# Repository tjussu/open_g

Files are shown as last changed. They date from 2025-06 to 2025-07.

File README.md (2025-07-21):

# OpenG Project

__Currently, the project is in the prototyping phase.__

## Overview

The goal of this project is to develop an open-source data logger for soaring and glider aerobatics. The hardware can be built by anyone interested and modified for their own purposes.

## Goals
Specific implementation goals are:

- A watchdog for structural load factors:
    - The load factors are measured in correspondence with the flight envelope (speed & load factors).
    - Critical events will be saved to memory.
    - The load factors can be displayed on a module.
- Path tracing for aerobatics:
    - Tracking of the flight path for training evaluation.
- Easy construction:
    - No difficult-to-solder SMD parts.
    - PCB can be ordered from an online EMS.
    - 3D-printable casing.
    - Construction cost under 450 €.
    - Easy modification.
- Documentation:
    - Hardware documentation.
    - Software documentation.
    - User manual.
    - Technical reference.

We aim to design the hardware in such a way that the system is compliant with EASA regulations. 

## Collaboration
The project is part of a master's thesis conducted at the _Dortmund University of Applied Sciences and Arts_ in cooperation with the _Luftsportfreunde 2000 Kamen/Dortmund club_.

Thanks to both!

## Future Updates
Further information will be provided in the near future.

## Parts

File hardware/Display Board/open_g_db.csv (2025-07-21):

Reference | Value | Qty | Footprint | DNP | Exclude from BOM | Exclude from Board | Datasheet | Mouser Price/Stock
C1,C2,C6,C7 | 0.1u | 4 | Capacitor_SMD:C_0805_2012Metric_Pad1.18x1.45mm_HandSolder |  |  |  | ~
C3 | 1u | 1 | Capacitor_SMD:C_0805_2012Metric_Pad1.18x1.45mm_HandSolder |  |  |  | ~
C4 | 10u | 1 | Capacitor_THT:CP_Radial_D5.0mm_P2.00mm |  |  |  | https://www.we-online.com/components/products/datasheet/860020672010.pdf
C5 | 22u | 1 | Capacitor_THT:CP_Radial_D5.0mm_P2.00mm |  |  |  | https://www.we-online.com/components/products/datasheet/860020672011.pdf
C8 | 22u | 1 | Capacitor_SMD:C_0805_2012Metric_Pad1.18x1.45mm_HandSolder |  |  |  | ~
C9 | 10u | 1 | Capacitor_THT:CP_Radial_D5.0mm_P2.00mm | Nicht bestücken |  |  | https://www.we-online.com/components/products/datasheet/860020672010.pdf
C10 | 22u | 1 | Capacitor_THT:CP_Radial_D5.0mm_P2.00mm | Nicht bestücken |  |  | https://www.we-online.com/components/products/datasheet/860020672011.pdf
C11 | 47n | 1 | Capacitor_SMD:C_0805_2012Metric_Pad1.18x1.45mm_HandSolder |  |  |  | ~
D2 | PWR_LED | 1 | LED_THT:LED_D3.0mm_Horizontal_O1.27mm_Z2.0mm_Clear |  |  |  | https://www.mouser.de/datasheet/2/216/WP710A10SGC-50126.pdf
D4,D5,D6 | LED_wh | 3 | LED_THT:LED_D3.0mm_Horizontal_O1.27mm_Z2.0mm_Clear |  |  |  | https://www.mouser.de/datasheet/2/414/OVLAW4CB7-3011932.pdf
D7,D8,D9 | LED_gr | 3 | LED_THT:LED_D3.0mm_Horizontal_O1.27mm_Z2.0mm_Clear |  |  |  | https://www.mouser.de/datasheet/2/216/WP710A10SGC-50126.pdf
D10,D11,D12,D13,D14,D15 | LED_or | 6 | LED_THT:LED_D3.0mm_Horizontal_O1.27mm_Z2.0mm_Clear |  |  |  | https://www.mouser.de/datasheet/2/216/WP710A10SGC-50126.pdf
D16 | LED_rd | 1 | LED_THT:LED_D3.0mm_Horizontal_O1.27mm_Z2.0mm_Clear |  |  |  | https://www.mouser.de/datasheet/2/216/WP710A10SGC-50126.pdf
F1 | Fuse | 1 | SamacSys_Parts:3557-2 |  |  |  | https://www.mouser.de/datasheet/2/215/M65p41-3517744.pdf
H1,H2 | MountingHole | 2 | MountingHole:MountingHole_5mm_Pad_Via |  | Von Bauteilliste ausgeschlossen |  | ~
J1 | DE9_Socket | 1 | SamacSys_Parts:NFD17E09SAFC1DA |  |  |  | ~
R1,R6,R9,R11,R12,R20,R21,R22,R43,R44,R45,R46,R47,R48,R49,R50,R51,R52 | 0R | 18 | Resistor_SMD:R_0805_2012Metric_Pad1.20x1.40mm_HandSolder | Nicht bestücken |  |  | ~
R2 | 510 | 1 | Resistor_SMD:R_0805_2012Metric_Pad1.20x1.40mm_HandSolder |  |  |  | ~
R3,R4 | 1k | 2 | Resistor_SMD:R_0805_2012Metric_Pad1.20x1.40mm_HandSolder |  |  |  | ~
R5,R7,R10,R17,R18,R19,R33,R34,R35,R36,R37,R38,R39,R40,R41,R42 | 10k | 16 | Resistor_SMD:R_0805_2012Metric_Pad1.20x1.40mm_HandSolder |  |  |  | ~
R8 | 100k | 1 | Resistor_SMD:R_0805_2012Metric_Pad1.20x1.40mm_HandSolder |  |  |  | ~
R13 | 0R | 1 | Resistor_SMD:R_0805_2012Metric_Pad1.20x1.40mm_HandSolder |  |  |  | ~
R14,R15,R16 | 82 | 3 | Resistor_SMD:R_0805_2012Metric_Pad1.20x1.40mm_HandSolder |  |  |  | ~
R23,R24,R25,R26,R27,R28,R29,R30,R31,R32 | 130 | 10 | Resistor_SMD:R_0805_2012Metric_Pad1.20x1.40mm_HandSolder |  |  |  | ~
TP1,TP2,TP3,TP4,TP5,TP6,TP7,TP8,TP9,TP10,TP11 | TestPoint | 11 | TestPoint:TestPoint_Pad_D2.5mm |  |  |  | ~
U1 | ESP32-WROOM-32E | 1 | RF_Module:ESP32-WROOM-32E |  |  |  | https://www.espressif.com/sites/default/files/documentation/esp32-wroom-32e_esp32-wroom-32ue_datasheet_en.pdf
U2 | MAX7318AWG+ | 1 | Package_SO:SOIC-24W_7.5x15.4mm_P1.27mm |  |  |  | https://www.mouser.de/datasheet/2/609/1/MAX7318-3470766.pdf
IC1,IC2 | TS04-66-75-BK-160-SMT | 2 | SamacSys_Parts:TS046675BK160SMT |  |  |  | https://www.sameskydevices.com/product/resource/supplyframepdf/ts04.pdf | https://www.mouser.co.uk/ProductDetail/CUI-Devices/TS04-66-75-BK-160-SMT?qs=A6eO%252BMLsxmR5CIauYOve0Q%3D%3D
S1 | 1MS1T1B4M7QES | 1 | SamacSys_Parts:1MS1T1B4M7QES |  |  |  | https://www.dailywell.com.tw/en/search/index.html?q=1MS1T1B4M7QES&type=all | https://www.mouser.co.uk/ProductDetail/Dailywell/1MS1T1B4M7QES?qs=B6kkDfuK7%2FAUibuiVO%252BdHA%3D%3D
Q1,Q2,Q3,Q4,Q5,Q6,Q7,Q8,Q9,Q10,Q11,Q12,Q13,Q14 | BC548A | 14 | SamacSys_Parts:BC548A |  |  |  | https://diotec.com/request/datasheet/bc546.pdf | https://www.mouser.co.uk/ProductDetail/Diotec-Semiconductor/BC548A?qs=OlC7AqGiEDn7ksXHluy35w%3D%3D
PS1 | N7803-1C | 1 | SamacSys_Parts:N78031C |  |  |  | https://www.meanwell.com/webapp/product/search.aspx?prod=N78 | https://www.mouser.co.uk/ProductDetail/MEAN-WELL/N7803-1C?qs=7D1LtPJG0i1K0F21XTLD8Q%3D%3D
PS2 | N7805-1PH | 1 | SamacSys_Parts:N78031C | Nicht bestücken |  |  | https://www.meanwell.com/webapp/product/search.aspx?prod=N78 | https://www.mouser.co.uk/ProductDetail/MEAN-WELL/N7805-1PH?qs=7D1LtPJG0i2yQtENgJv8Bw%3D%3D
D3 | MMBD352WT1G | 1 | SamacSys_Parts:SOT65P220X100-3N | Nicht bestücken |  |  | https://www.onsemi.com/pub/Collateral/MMBD352WT1-D.PDF | https://www.mouser.co.uk/ProductDetail/ON-Semiconductor/MMBD352WT1G?qs=HVbQlW5zcXX4Hbj73AzZEQ%3D%3D
LS1 | CMI-0955-03TH | 1 | SamacSys_Parts:CMI095503TH |  |  |  | https://www.sameskydevices.com/product/resource/supplyframepdf/cmi-0955-03th.pdf | https://www.mouser.co.uk/ProductDetail/Same-Sky/CMI-0955-03TH?qs=olJun0bQHM8qnyh30s0SwQ%3D%3D
D1 | STPS8H100D | 1 | SamacSys_Parts:TO515P460X1020X2008-2P |  |  |  | http://www.st.com/web/en/resource/technical/document/datasheet/CD00001293.pdf | https://www.mouser.co.uk/ProductDetail/STMicroelectronics/STPS8H100D?qs=JV7lzlMm3yLc5UJZDGTzhw%3D%3D
J2 | 2-1825027-0 | 1 | SamacSys_Parts:218250270 |  |  |  | https://www.mouser.de/datasheet/2/418/8/ENG_CD_1825027_H1-2020946.pdf | https://www.mouser.co.uk/ProductDetail/TE-Connectivity-PB/2-1825027-0?qs=sLzr0G66nuqhlS4AJQmBZQ%3D%3D

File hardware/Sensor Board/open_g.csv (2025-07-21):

Reference | Value | Qty | Footprint | DNP | Exclude from BOM | Exclude from Board | Datasheet | Mouser Price/Stock
TP1,TP2,TP3,TP4,TP5,TP6,TP7,TP8,TP9,TP10,TP11,TP12,TP13,TP14,TP15,TP16 | TestPoint | 16 | TestPoint:TestPoint_Pad_D2.5mm |  |  |  | ~
R4,R5,R6,R7,R8,R11,R13,R15,R16,R17,R22,R23,R25 | 0R | 13 | Resistor_SMD:R_0805_2012Metric_Pad1.20x1.40mm_HandSolder |  |  |  | ~
R12,R14,R18,R19 | 1k | 4 | Resistor_SMD:R_0805_2012Metric_Pad1.20x1.40mm_HandSolder | Nicht bestücken |  |  | ~
R1,R2,R9,R10 | 0R | 4 | Resistor_SMD:R_0805_2012Metric_Pad1.20x1.40mm_HandSolder | Nicht bestücken |  |  | ~
R20,R21,R24 | 1k | 3 | Resistor_SMD:R_0805_2012Metric_Pad1.20x1.40mm_HandSolder |  |  |  | ~
C1,C4,C6 | 0.1u | 3 | Capacitor_SMD:C_0805_2012Metric_Pad1.18x1.45mm_HandSolder |  |  |  | ~
JP1,JP2 | SolderJumper_3_Open | 2 | Jumper:SolderJumper-3_P2.0mm_Open_TrianglePad1.0x1.5mm |  | Von Bauteilliste ausgeschlossen |  | ~
IC1,IC2 | TS04-66-75-BK-160-SMT | 2 | SamacSys_Parts:TS046675BK160SMT |  |  |  | https://www.sameskydevices.com/product/resource/supplyframepdf/ts04.pdf | https://www.mouser.co.uk/ProductDetail/CUI-Devices/TS04-66-75-BK-160-SMT?qs=A6eO%252BMLsxmR5CIauYOve0Q%3D%3D
H1,H2 | MountingHole | 2 | MountingHole:MountingHole_5mm_Pad_Via |  | Von Bauteilliste ausgeschlossen |  | ~
U1 | ESP32-WROOM-32E | 1 | RF_Module:ESP32-WROOM-32D |  |  |  | https://www.espressif.com/sites/default/files/documentation/esp32-wroom-32e_esp32-wroom-32ue_datasheet_en.pdf
R3 | 10k | 1 | Resistor_SMD:R_0805_2012Metric_Pad1.20x1.40mm_HandSolder |  |  |  | ~
PS1 | N7803-1C | 1 | SamacSys_Parts:N78031C |  |  |  | https://www.meanwell.com/webapp/product/search.aspx?prod=N78 | https://www.mouser.co.uk/ProductDetail/MEAN-WELL/N7803-1C?qs=7D1LtPJG0i1K0F21XTLD8Q%3D%3D
J5 | 1861975 | 1 | SamacSys_Parts:PC1861975 |  |  |  | http://www.phoenixcontact.com/de/produkte/1861975/pdf | https://www.mouser.co.uk/ProductDetail/Phoenix-Contact/1861975?qs=tlR8i4ZVbUeb8cFKQBJmmw%3D%3D
J4 | Conn_01x05_Socket | 1 | Connector_PinSocket_2.54mm:PinSocket_1x05_P2.54mm_Vertical |  |  |  | ~
J3 | Conn_01x09_Socket | 1 | Connector_PinSocket_2.54mm:PinSocket_1x09_P2.54mm_Vertical |  |  |  | ~
J2 | DM3CS-SF | 1 | SamacSys:DM3CSSF |  |  |  | https://datasheet.lcsc.com/szlcsc/Hirose-HRS-DM3CS-SF_C202111.pdf | https://www.mouser.co.uk/ProductDetail/Hirose-Connector/DM3CS-SF?qs=tTj%252BmQ3KZwbB9K5zh89Rcw%3D%3D
J1 | DE9_Socket | 1 | SamacSys_Parts:NFD17E09SAFC1DA |  |  |  | https://cdn.amphenol-cs.com/media/wysiwyg/files/documentation/datasheet/inputoutput/io_dsub_standard_density_nfd17.pdf
IC3 | 5525DSO-DB001DS | 1 | Package_SO:SOIC-14W_7.5x9mm_P1.27mm |  |  |  | https://www.te.com/commerce/DocumentDelivery/DDEController?Action=srchrtrv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 | https://www.mouser.co.uk/ProductDetail/Measurement-Specialties/5525DSO-DB001DS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
C8 | 100n | 1 | Capacitor_SMD:C_0805_2012Metric_Pad1.18x1.45mm_HandSolder |  |  |  | ~
C7 | 22u | 1 | Capacitor_SMD:C_0805_2012Metric_Pad1.18x1.45mm_HandSolder |  |  |  | ~
C5 | 1u | 1 | Capacitor_SMD:C_0805_2012Metric_Pad1.18x1.45mm_HandSolder |  |  |  | ~
C3 | 22u | 1 | Capacitor_THT:CP_Radial_D5.0mm_P2.00mm |  |  |  | https://www.mouser.de/ProductDetail/Wurth-Elektronik/860010272001?qs=0KOYDY2FL2%252BONnZKgxEFWA%3D%3D
C2 | 10u | 1 | Capacitor_THT:CP_Radial_D5.0mm_P2.00mm |  |  |  | https://www.we-online.com/components/products/datasheet/860020672010.pdf

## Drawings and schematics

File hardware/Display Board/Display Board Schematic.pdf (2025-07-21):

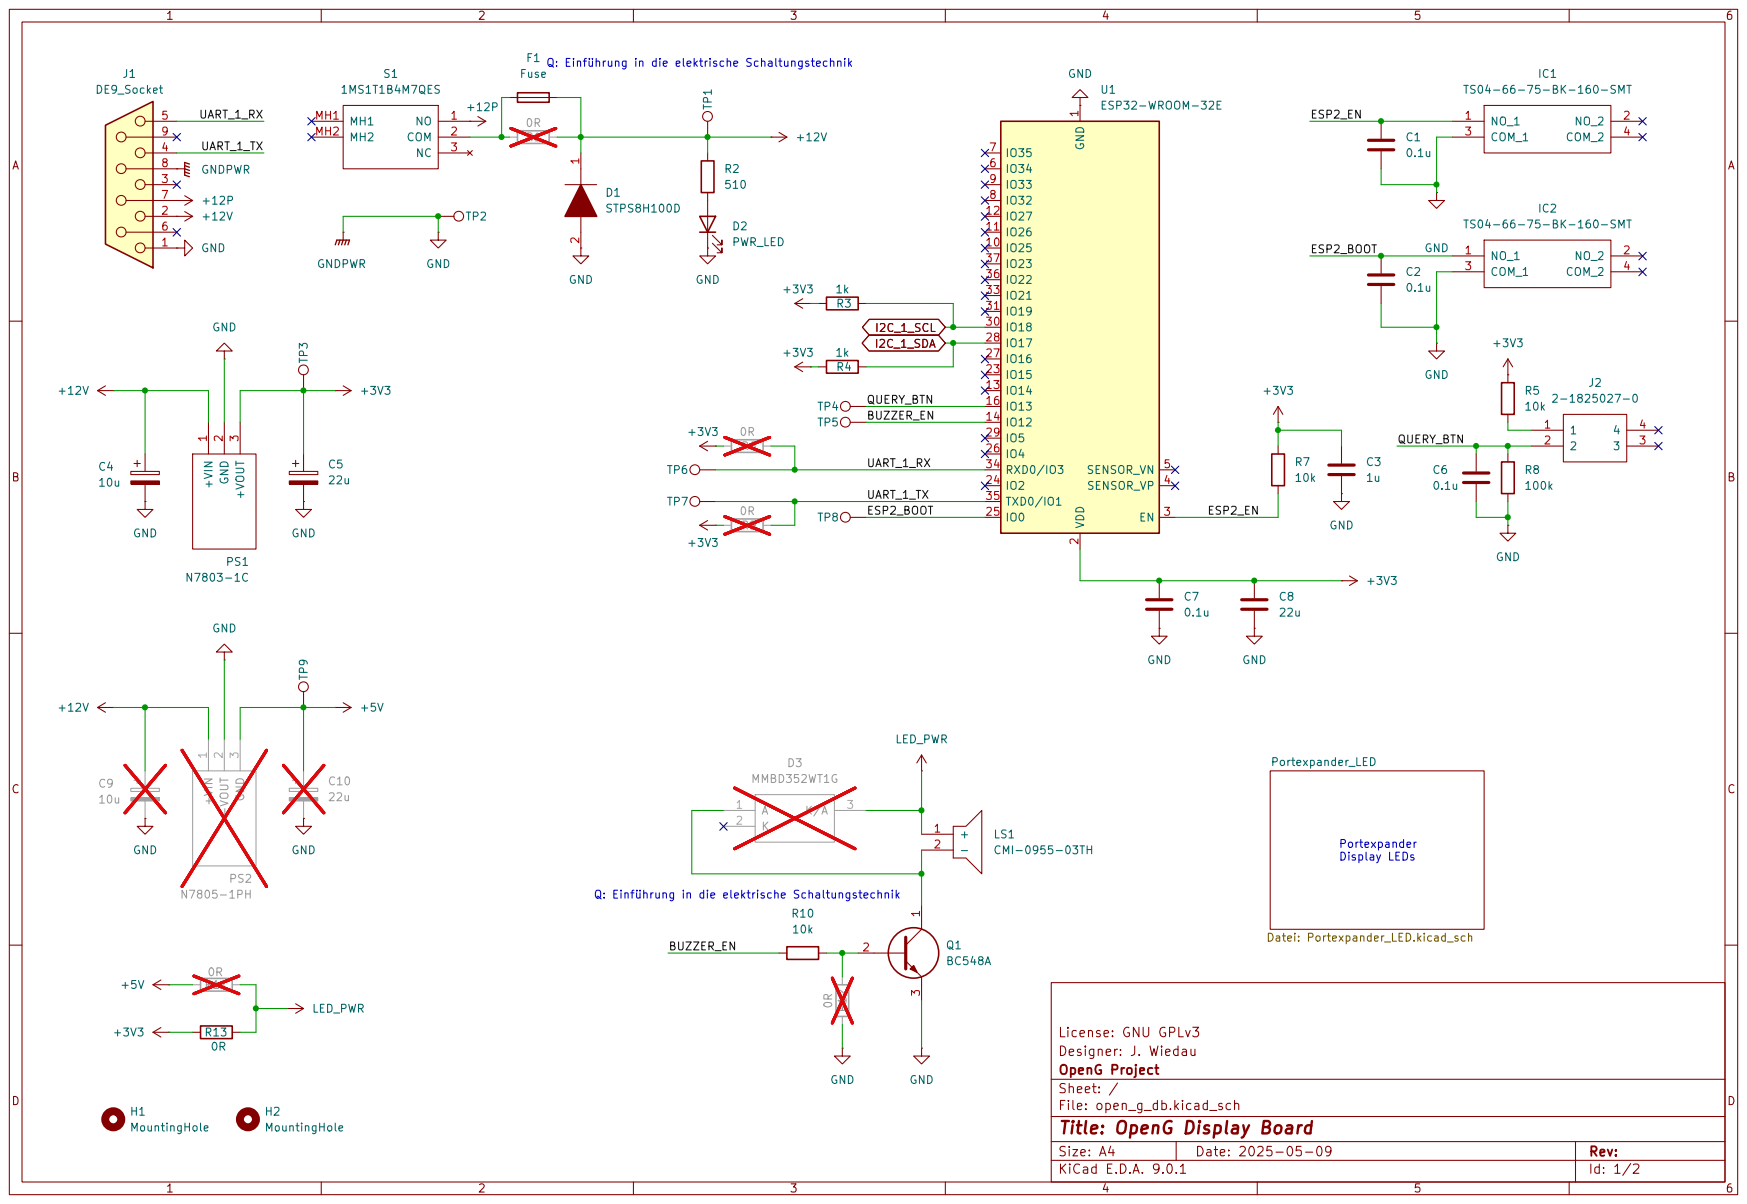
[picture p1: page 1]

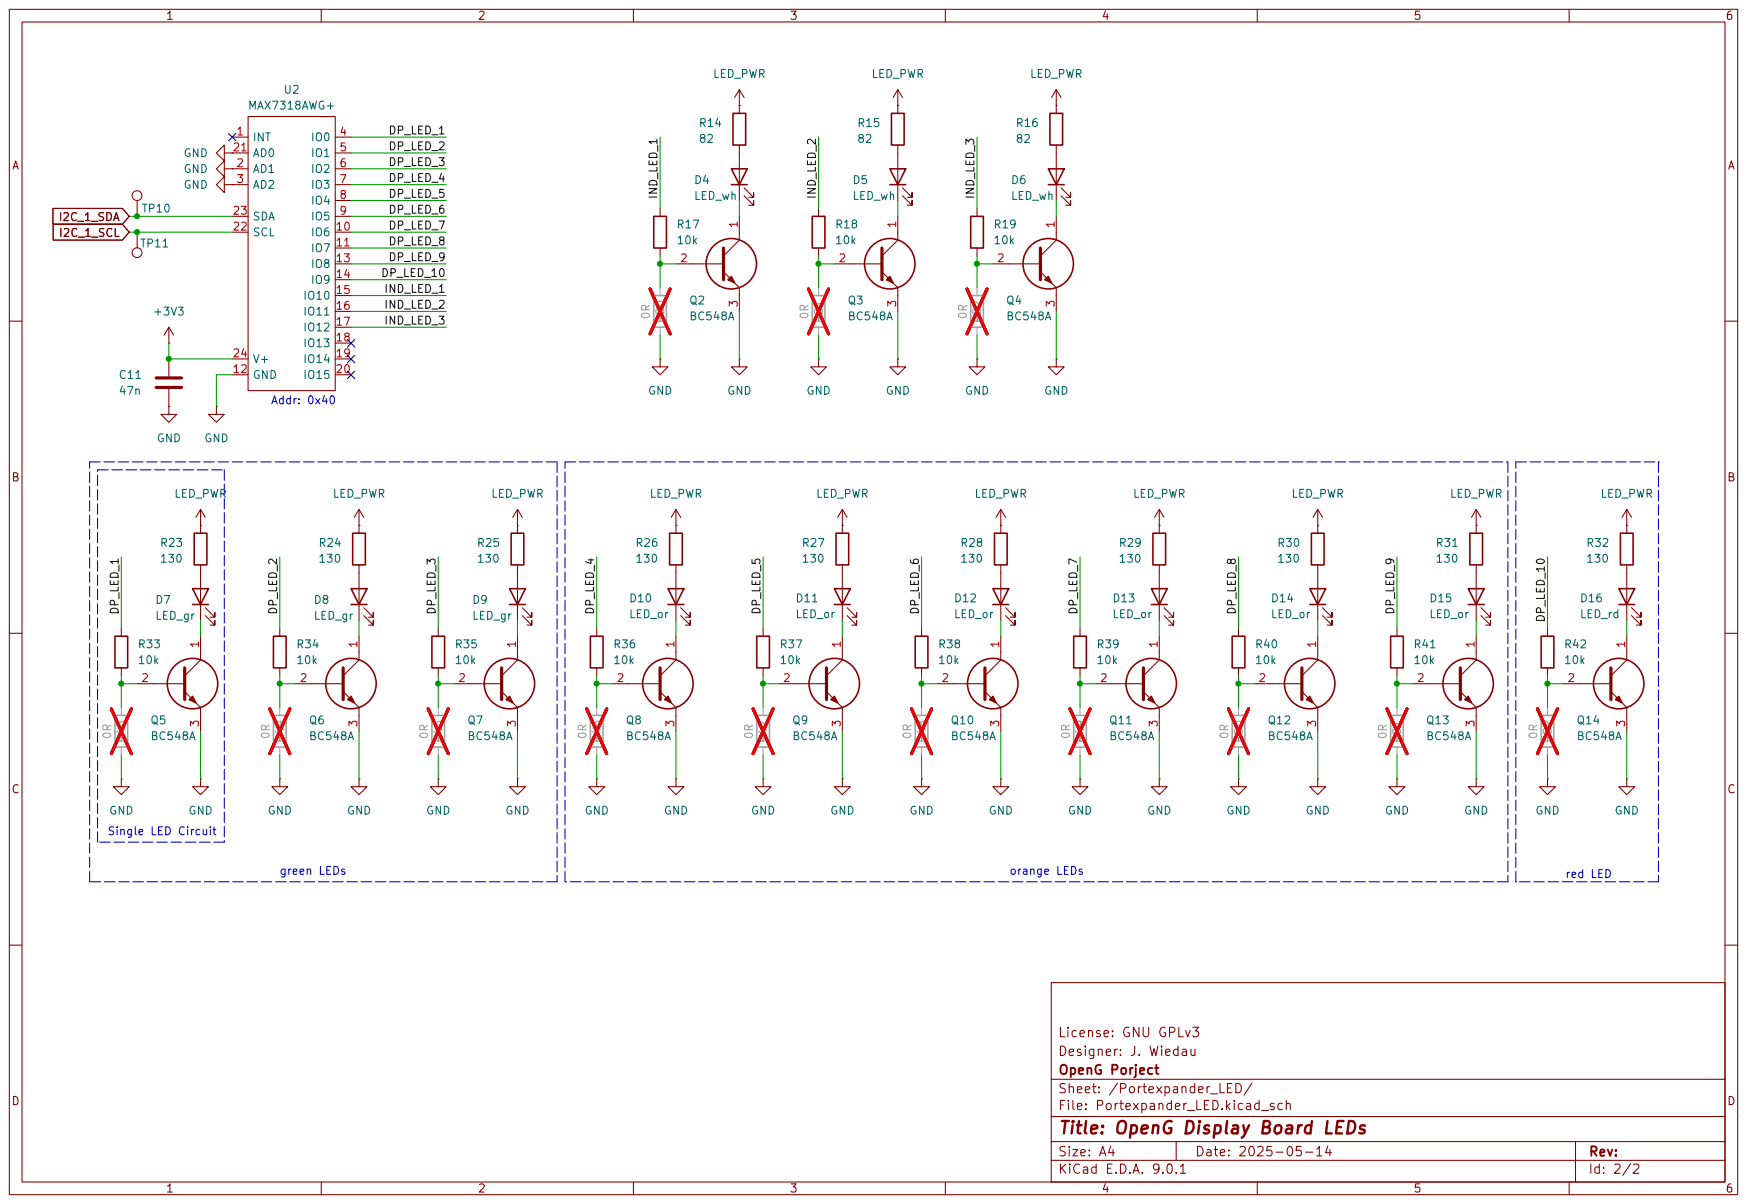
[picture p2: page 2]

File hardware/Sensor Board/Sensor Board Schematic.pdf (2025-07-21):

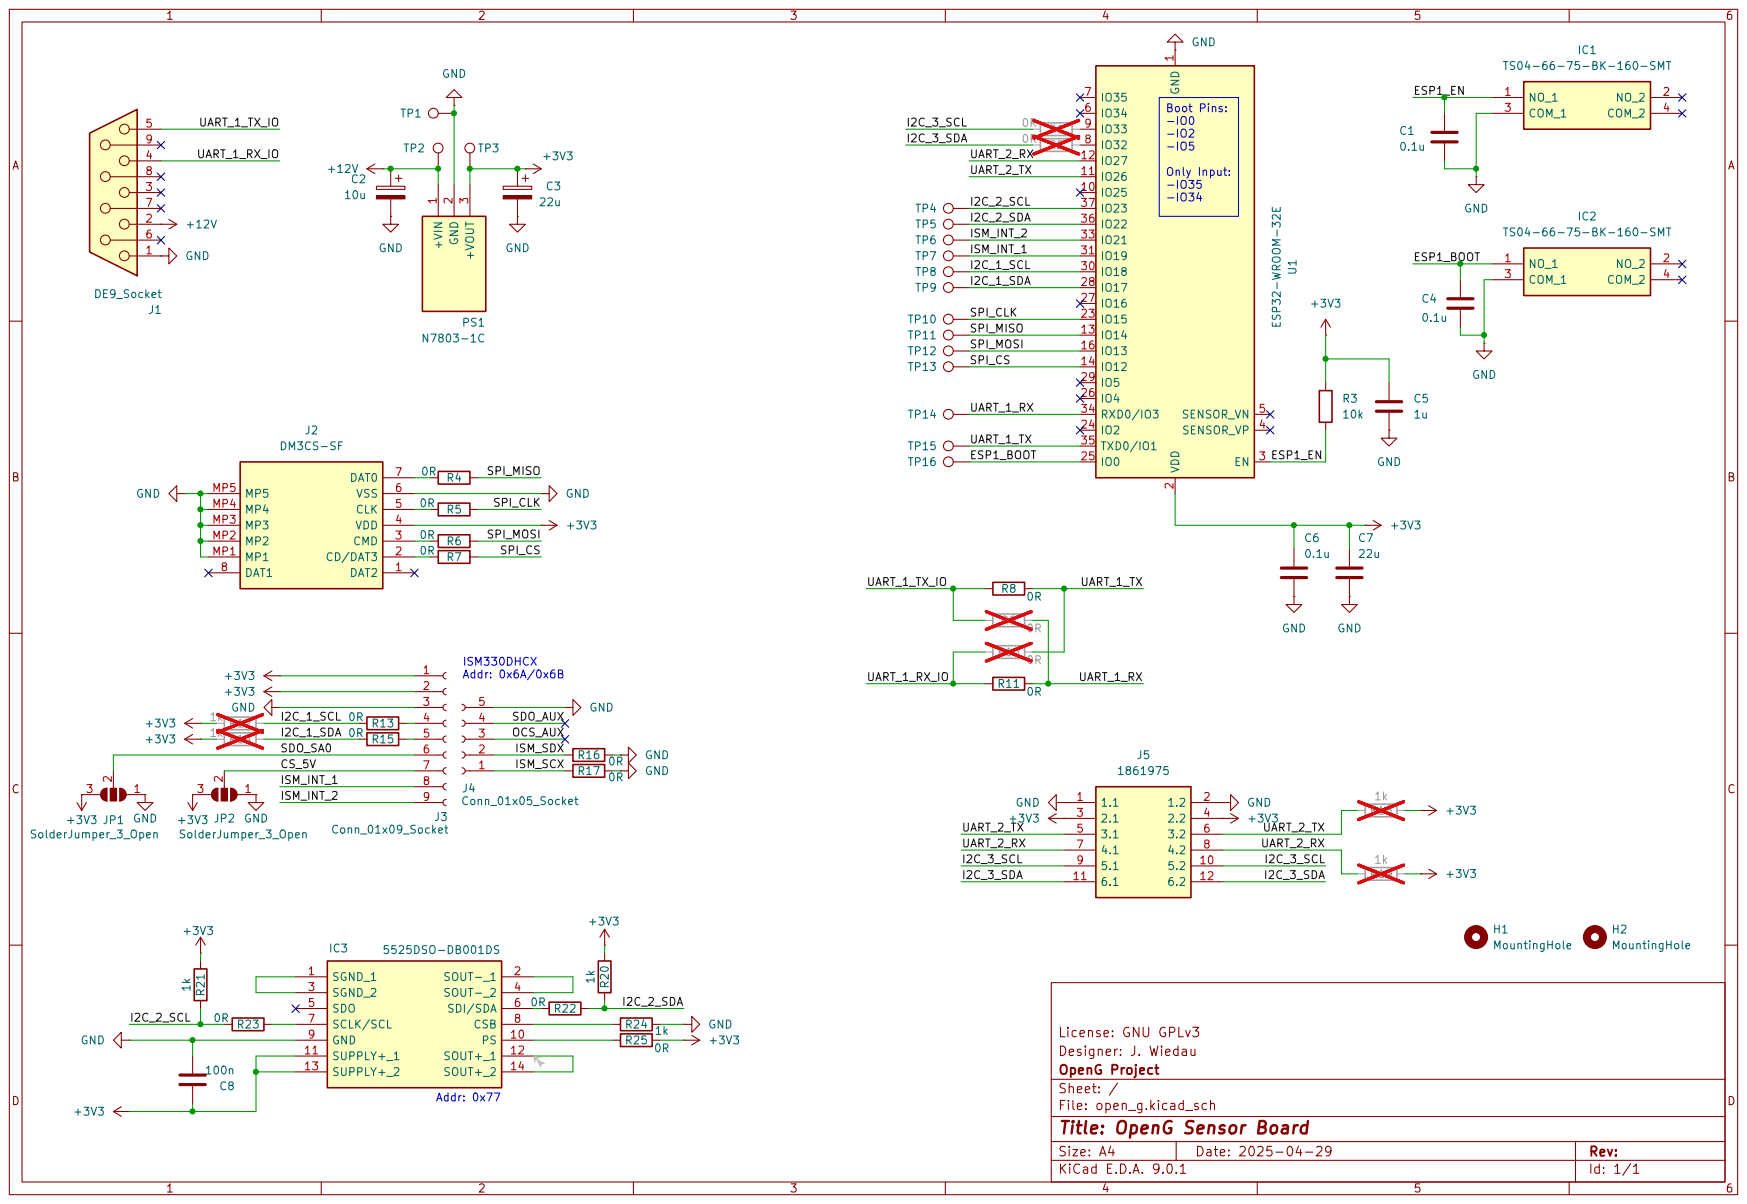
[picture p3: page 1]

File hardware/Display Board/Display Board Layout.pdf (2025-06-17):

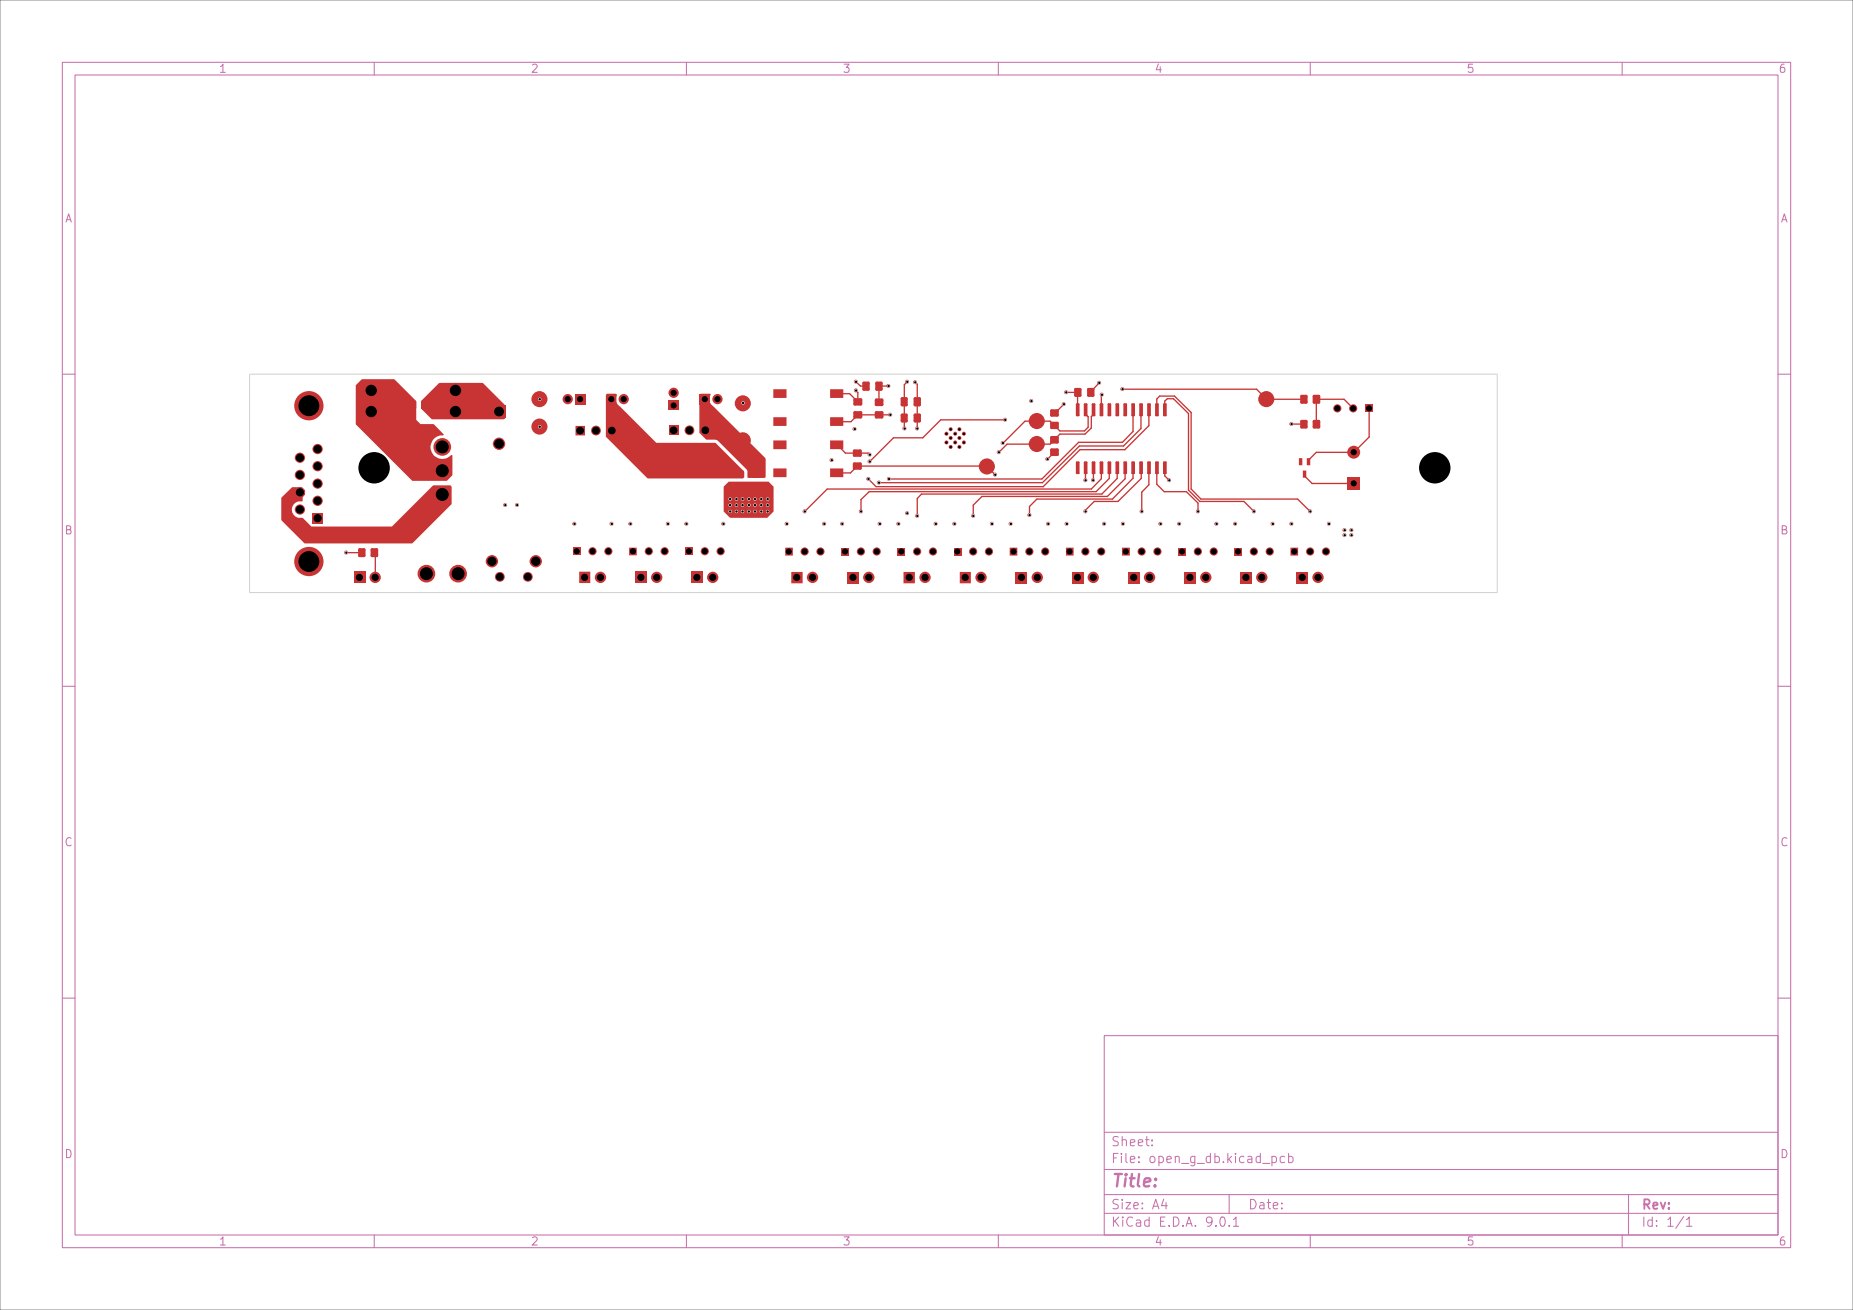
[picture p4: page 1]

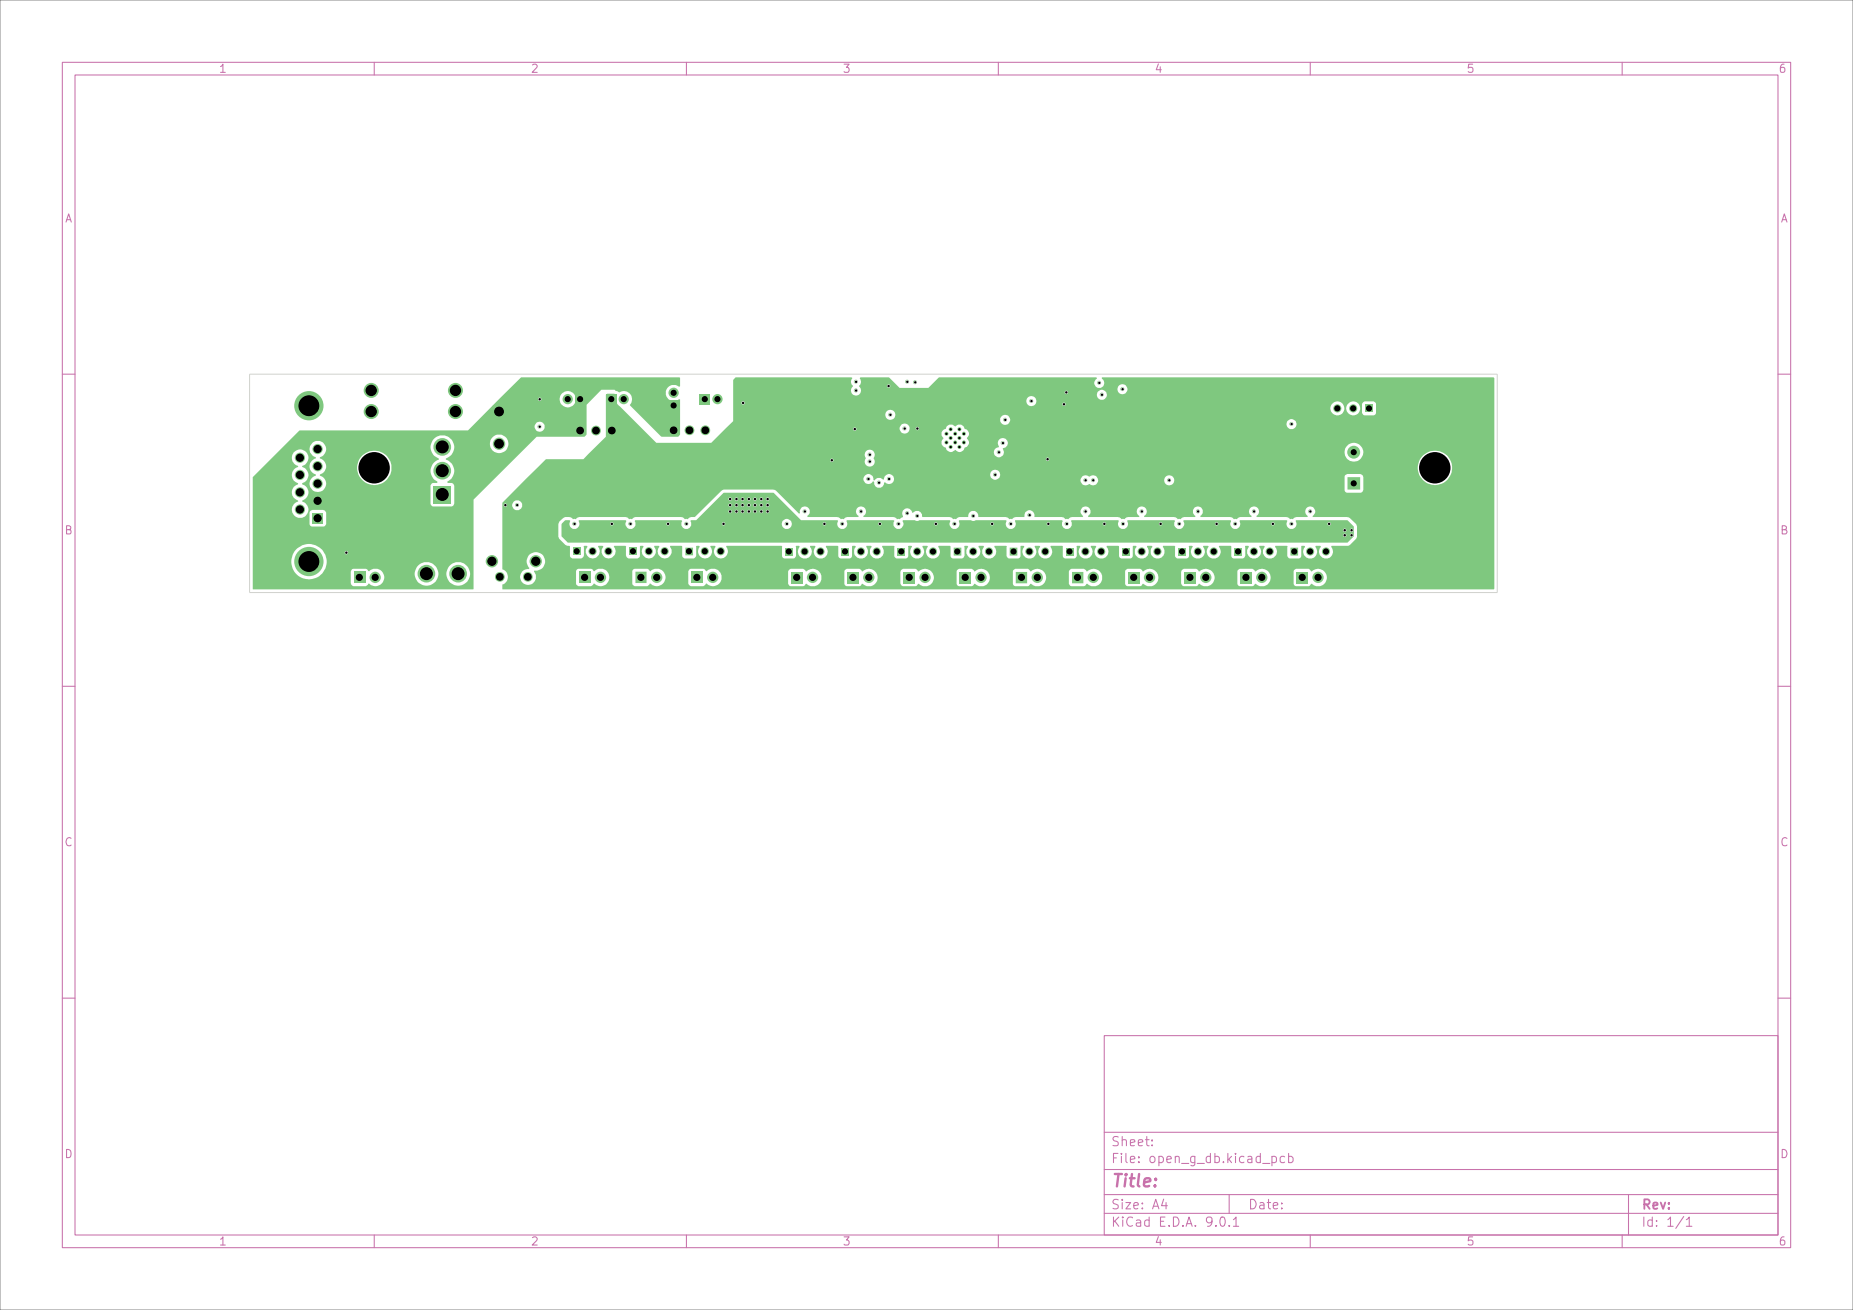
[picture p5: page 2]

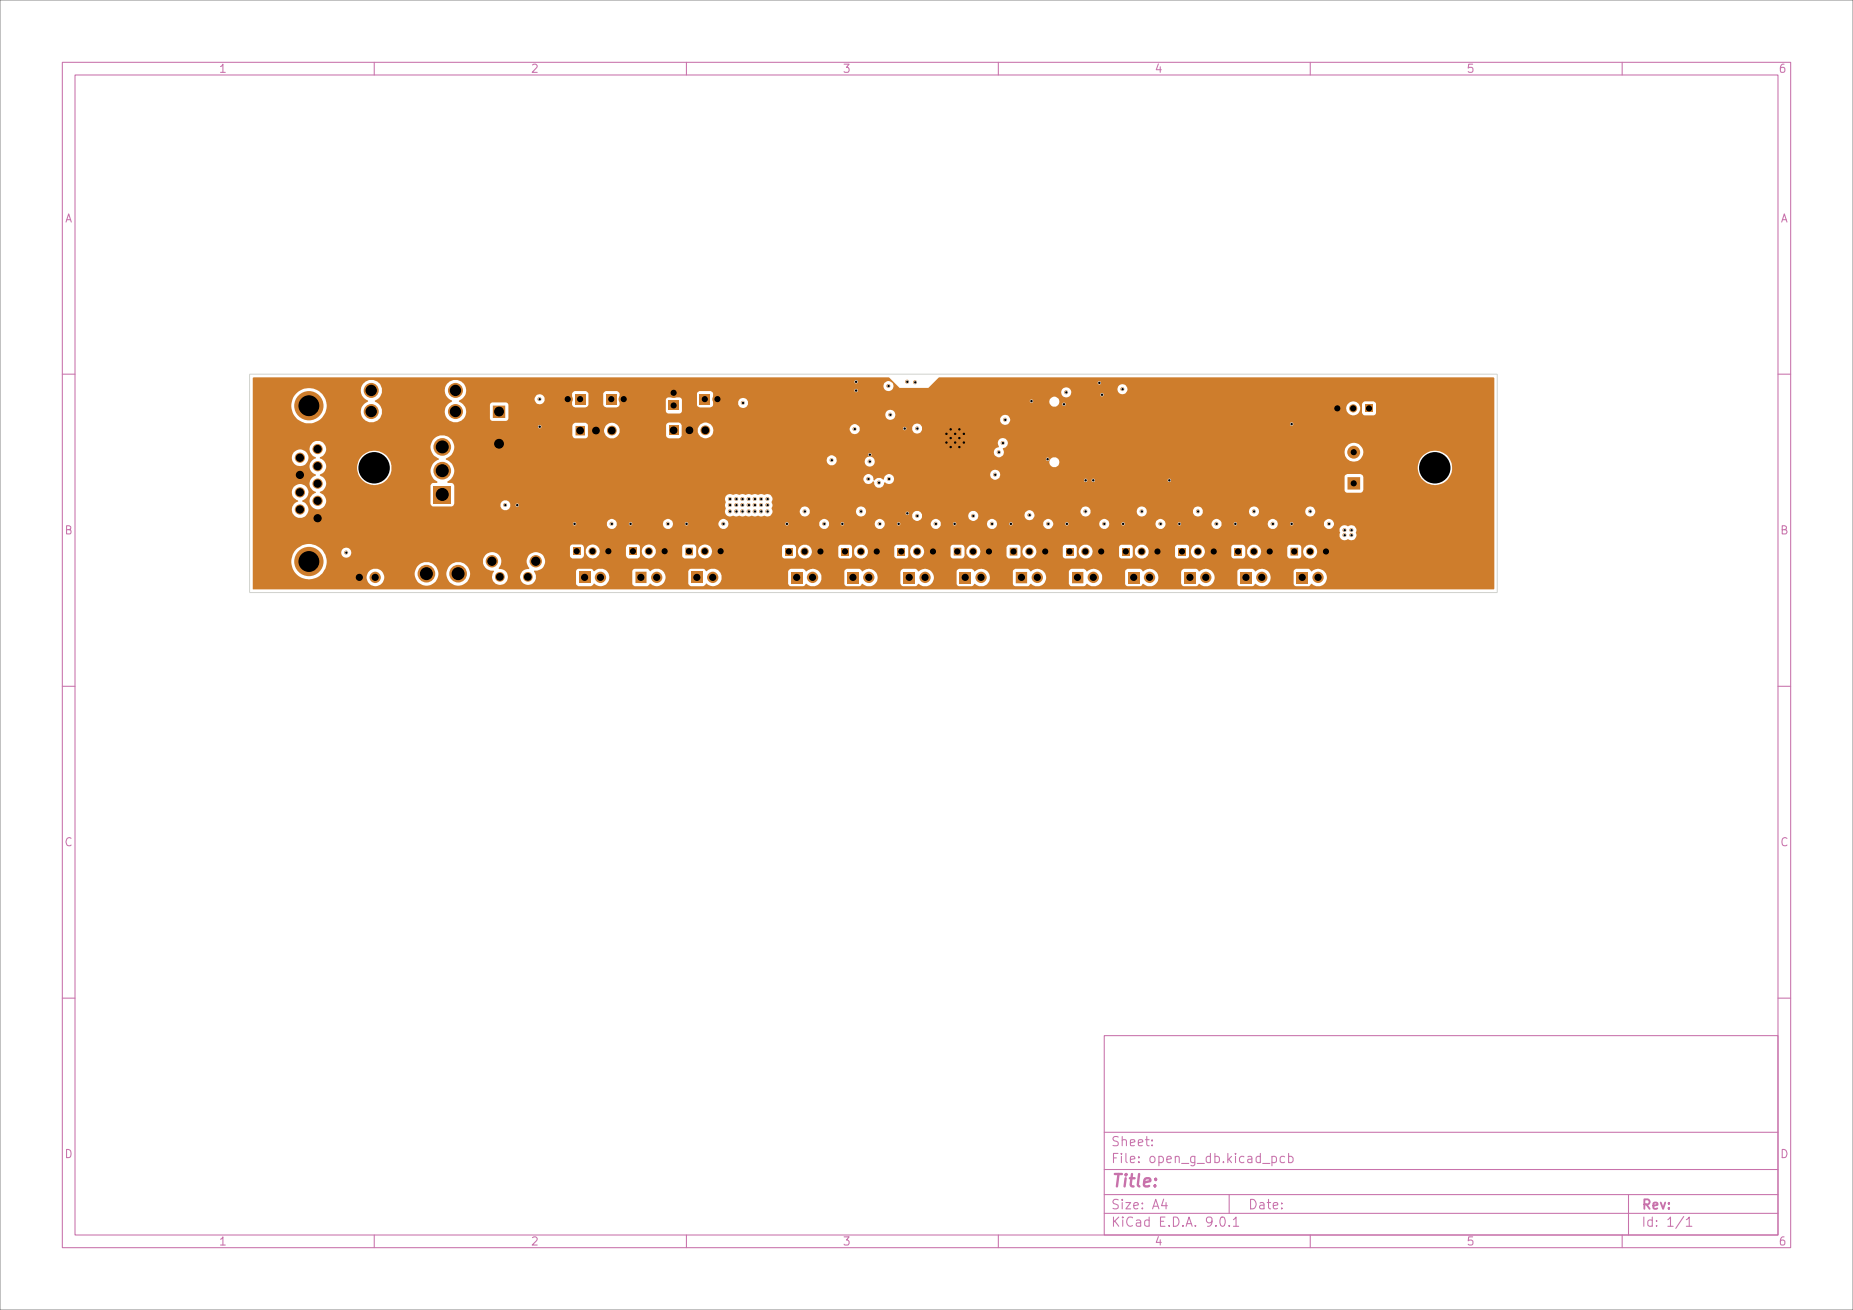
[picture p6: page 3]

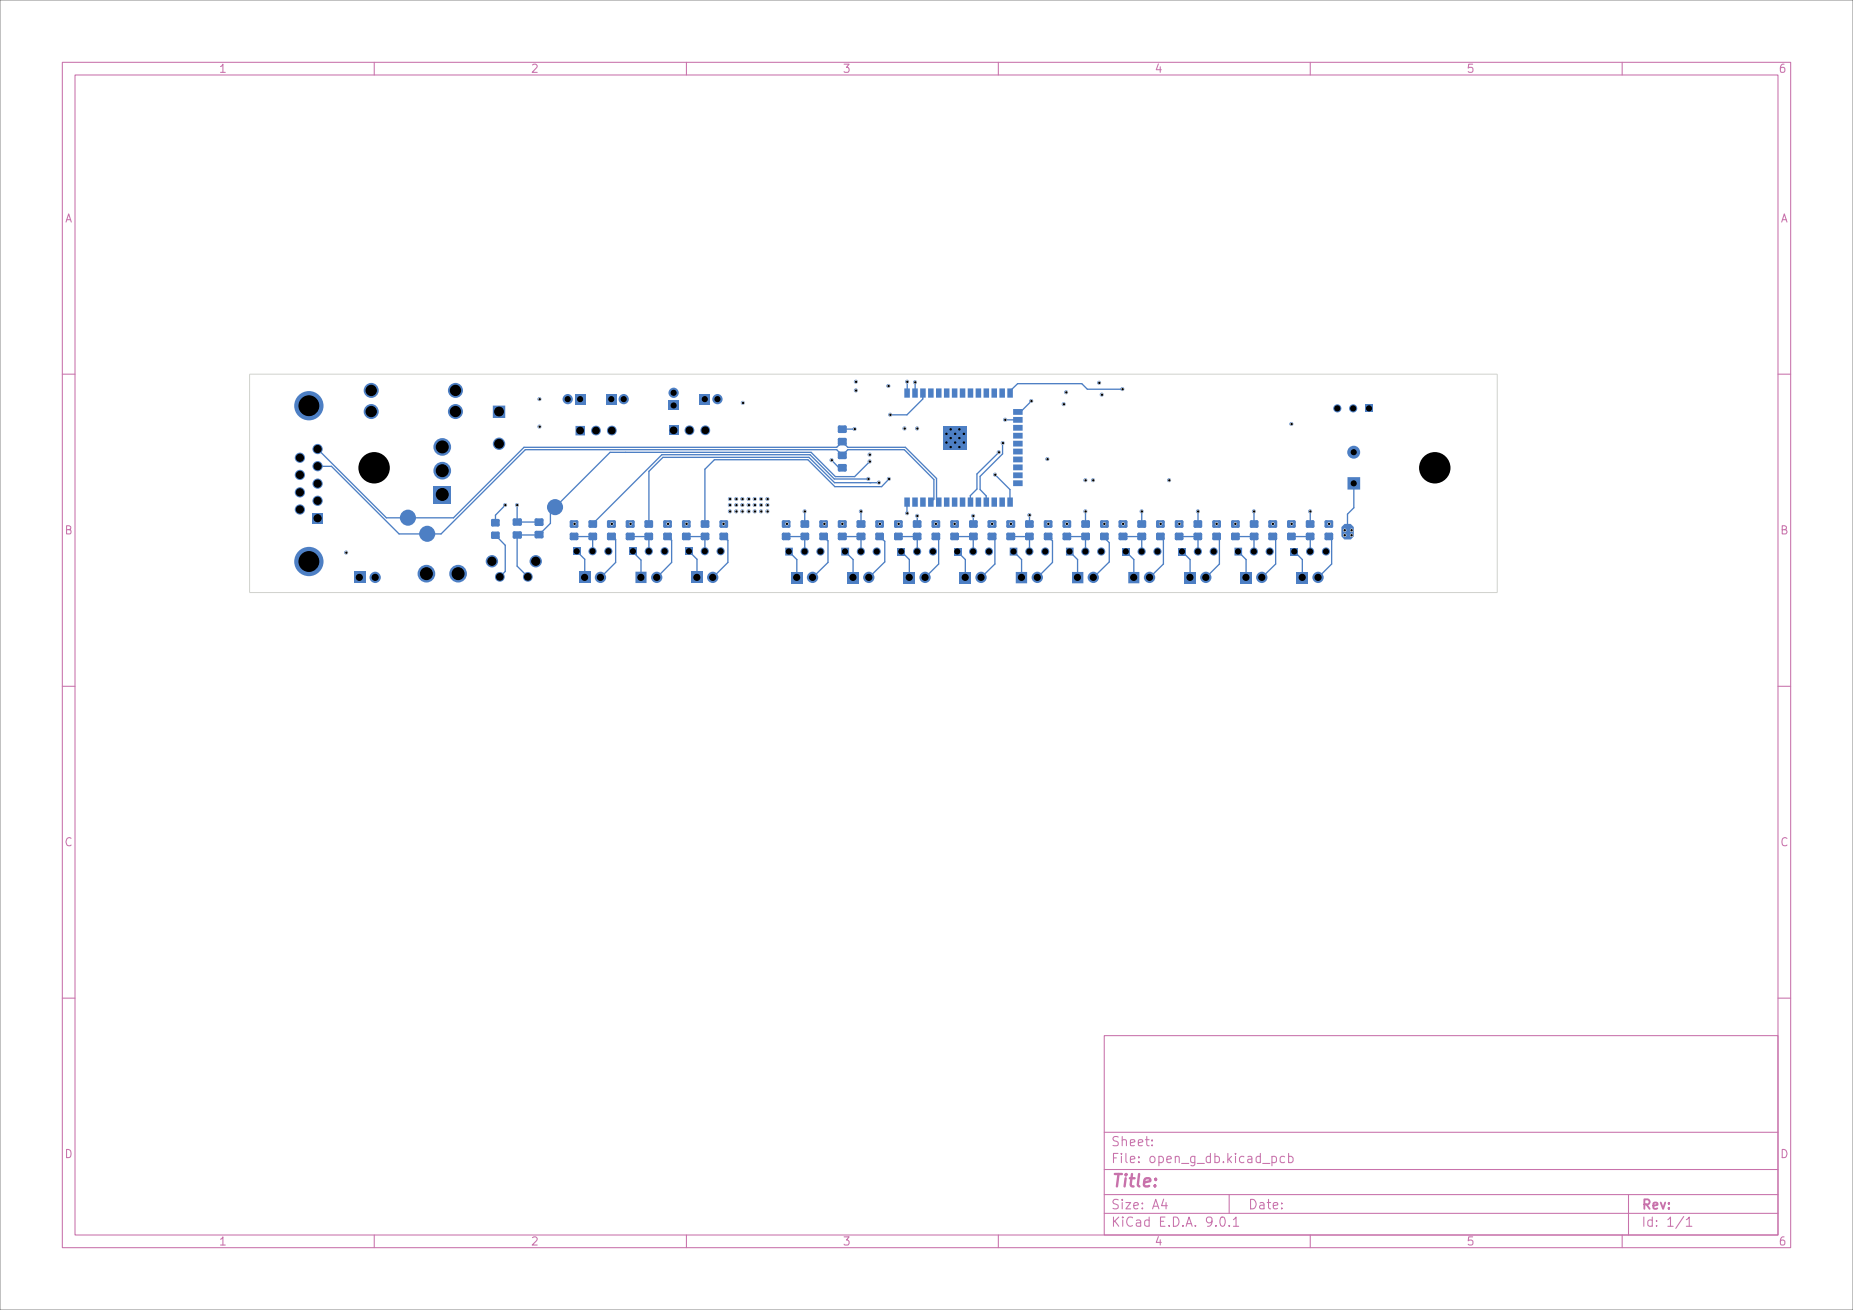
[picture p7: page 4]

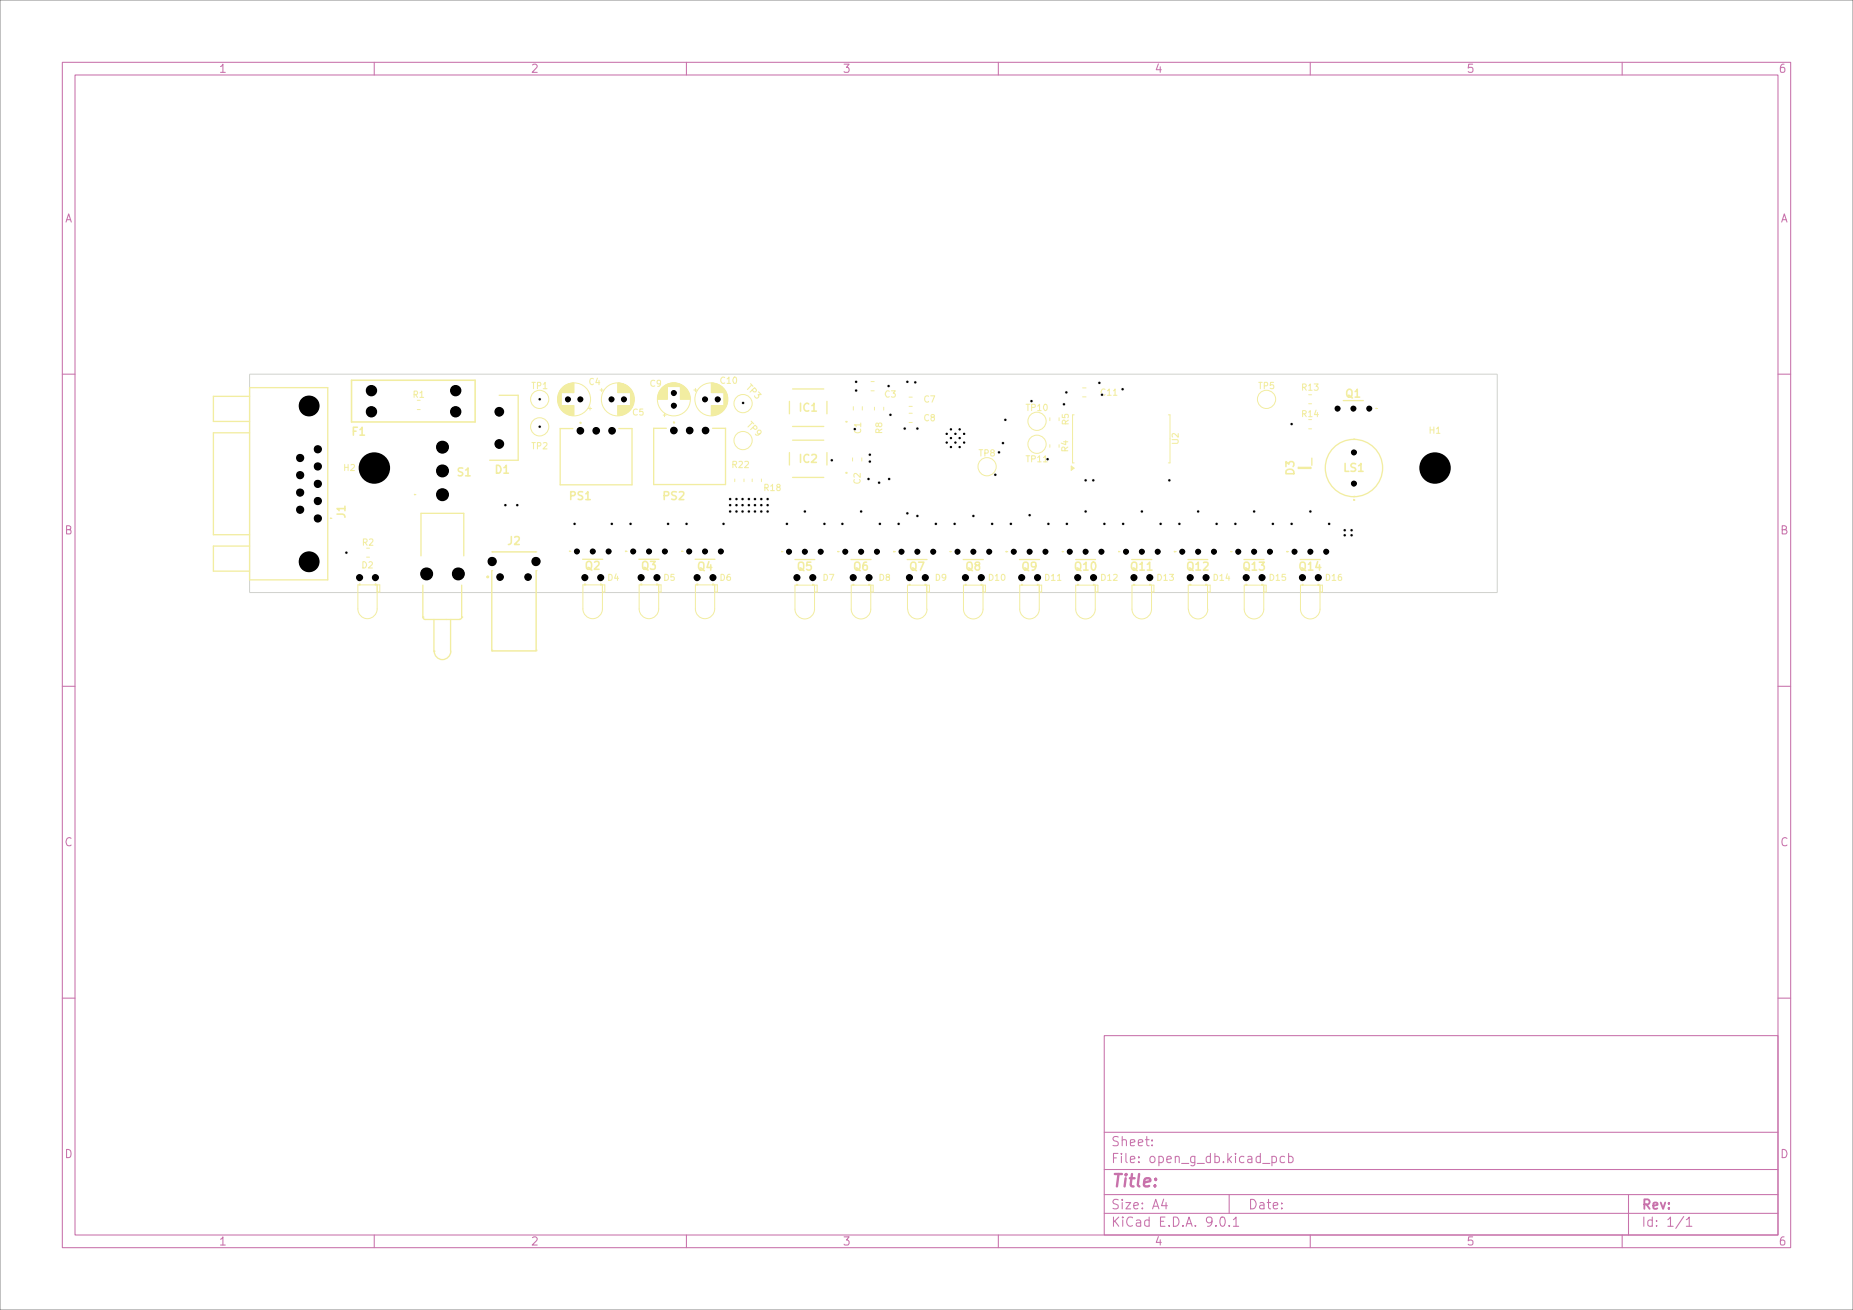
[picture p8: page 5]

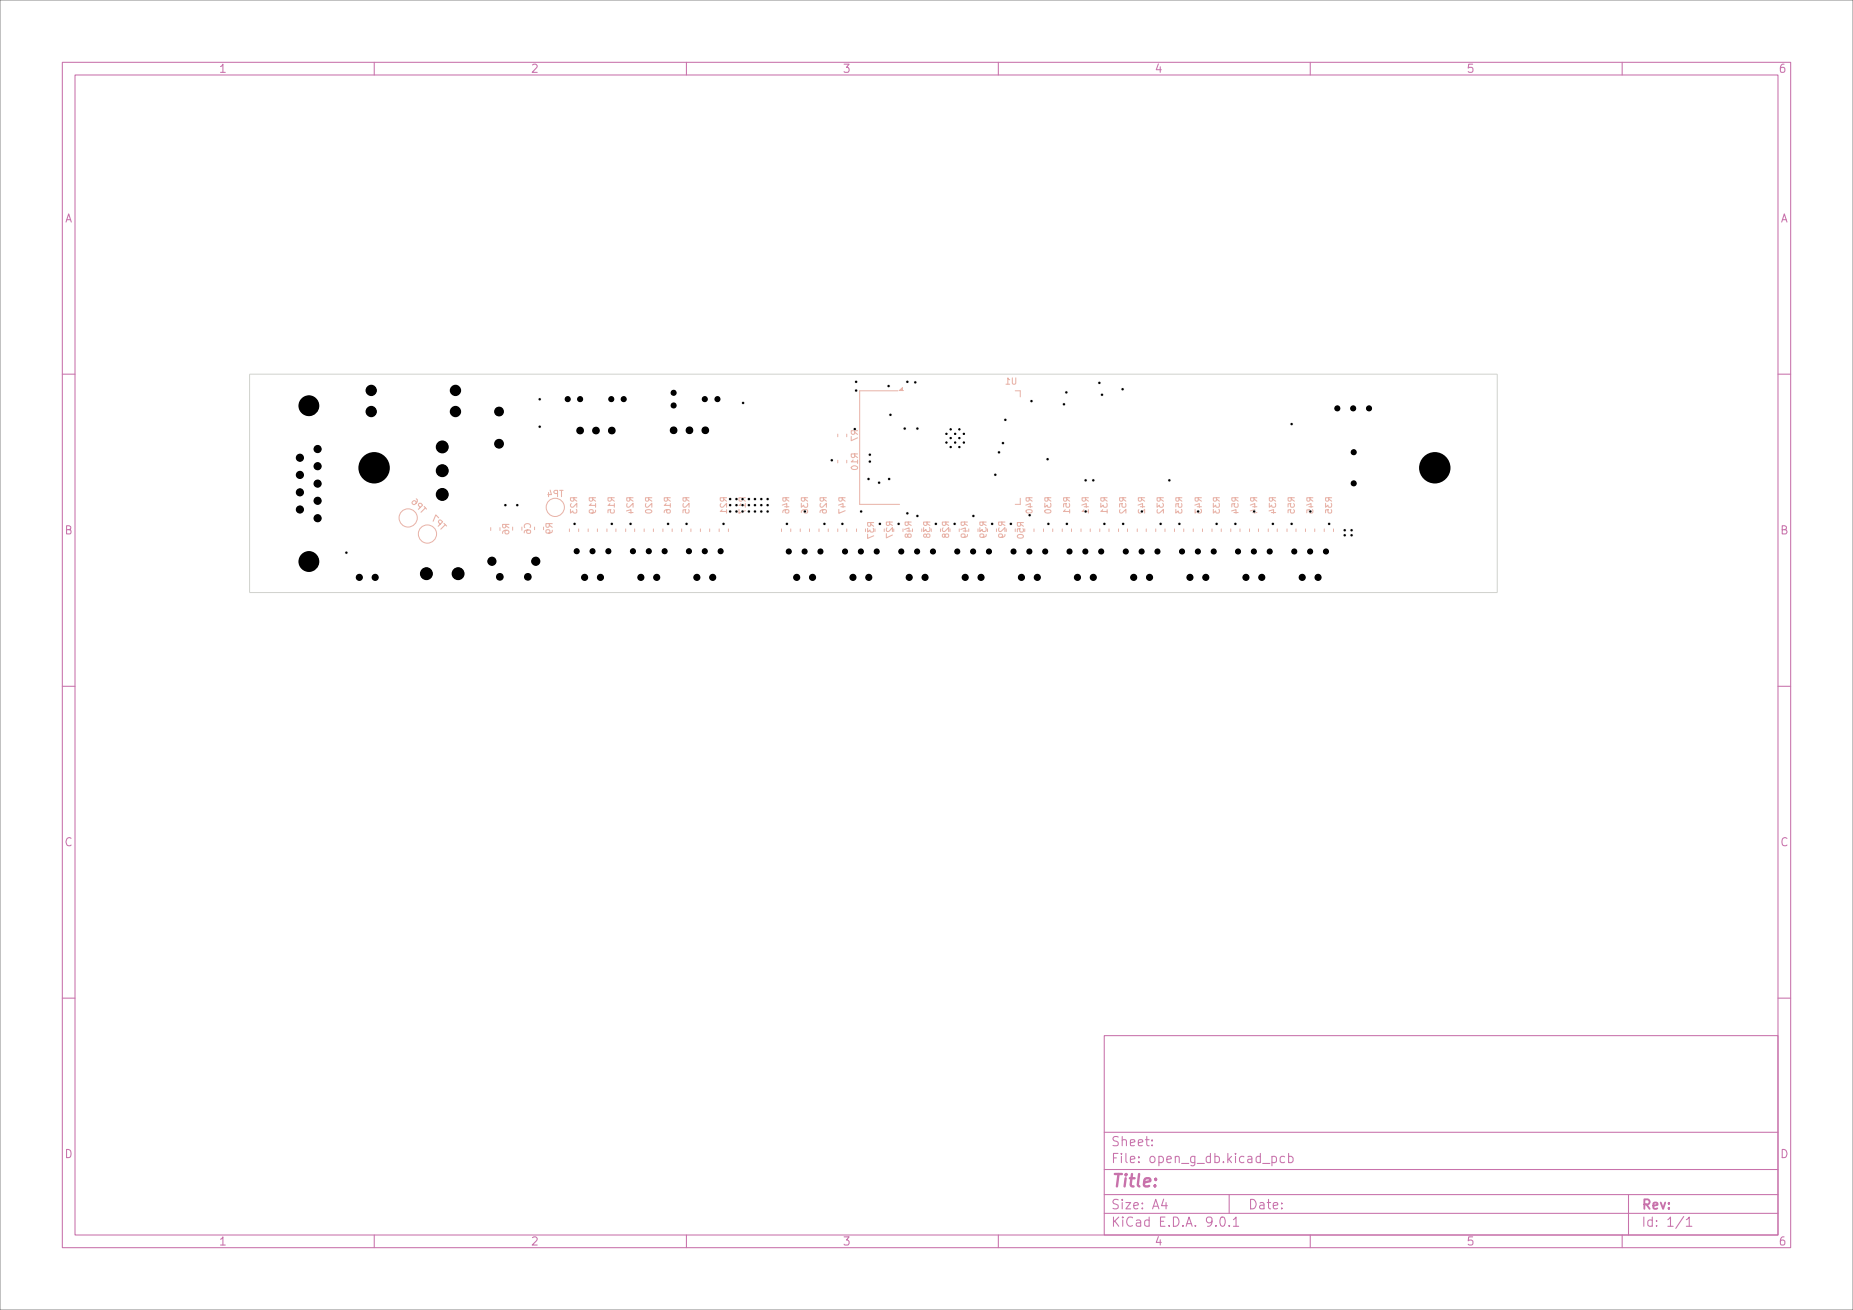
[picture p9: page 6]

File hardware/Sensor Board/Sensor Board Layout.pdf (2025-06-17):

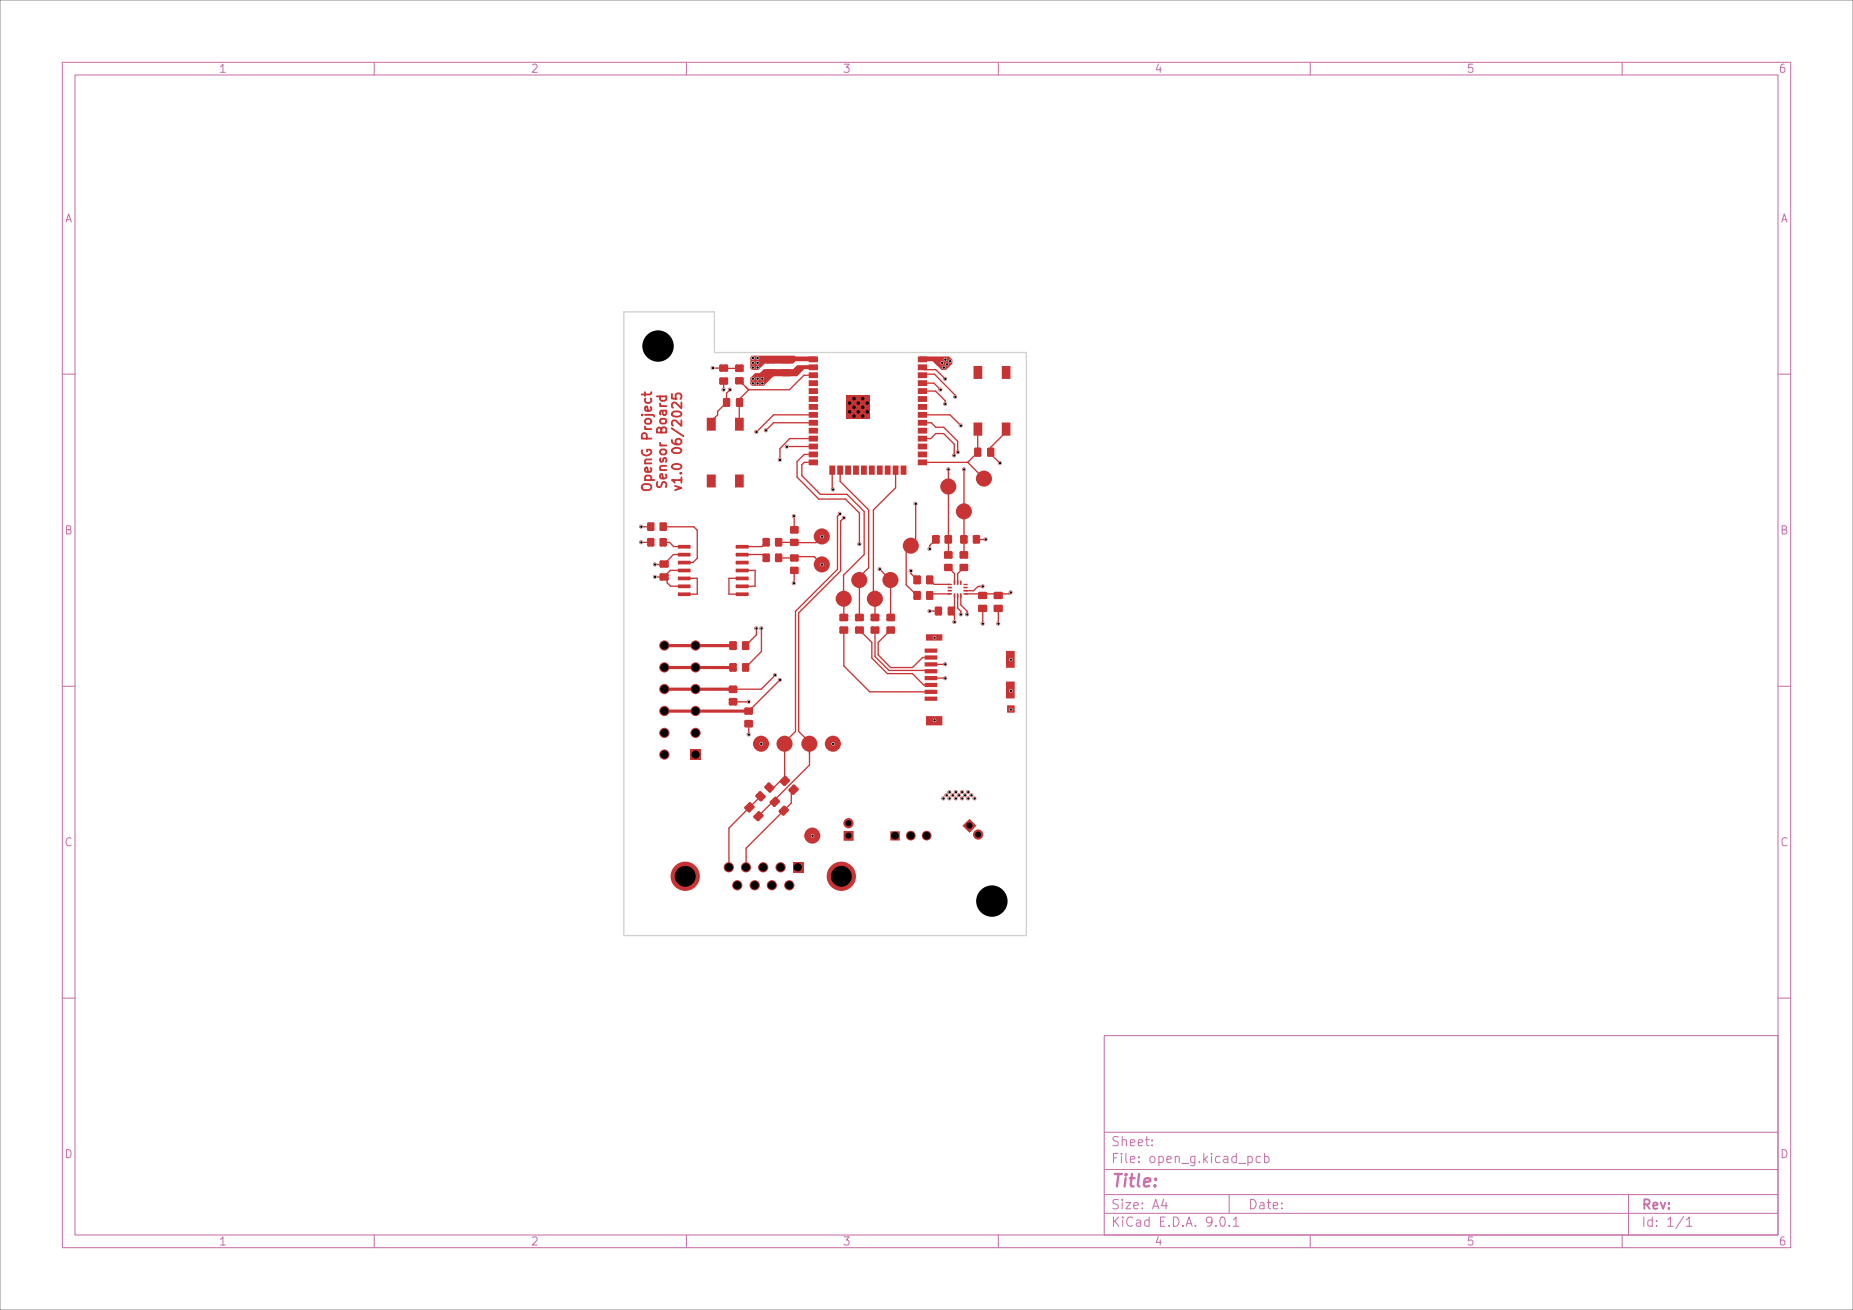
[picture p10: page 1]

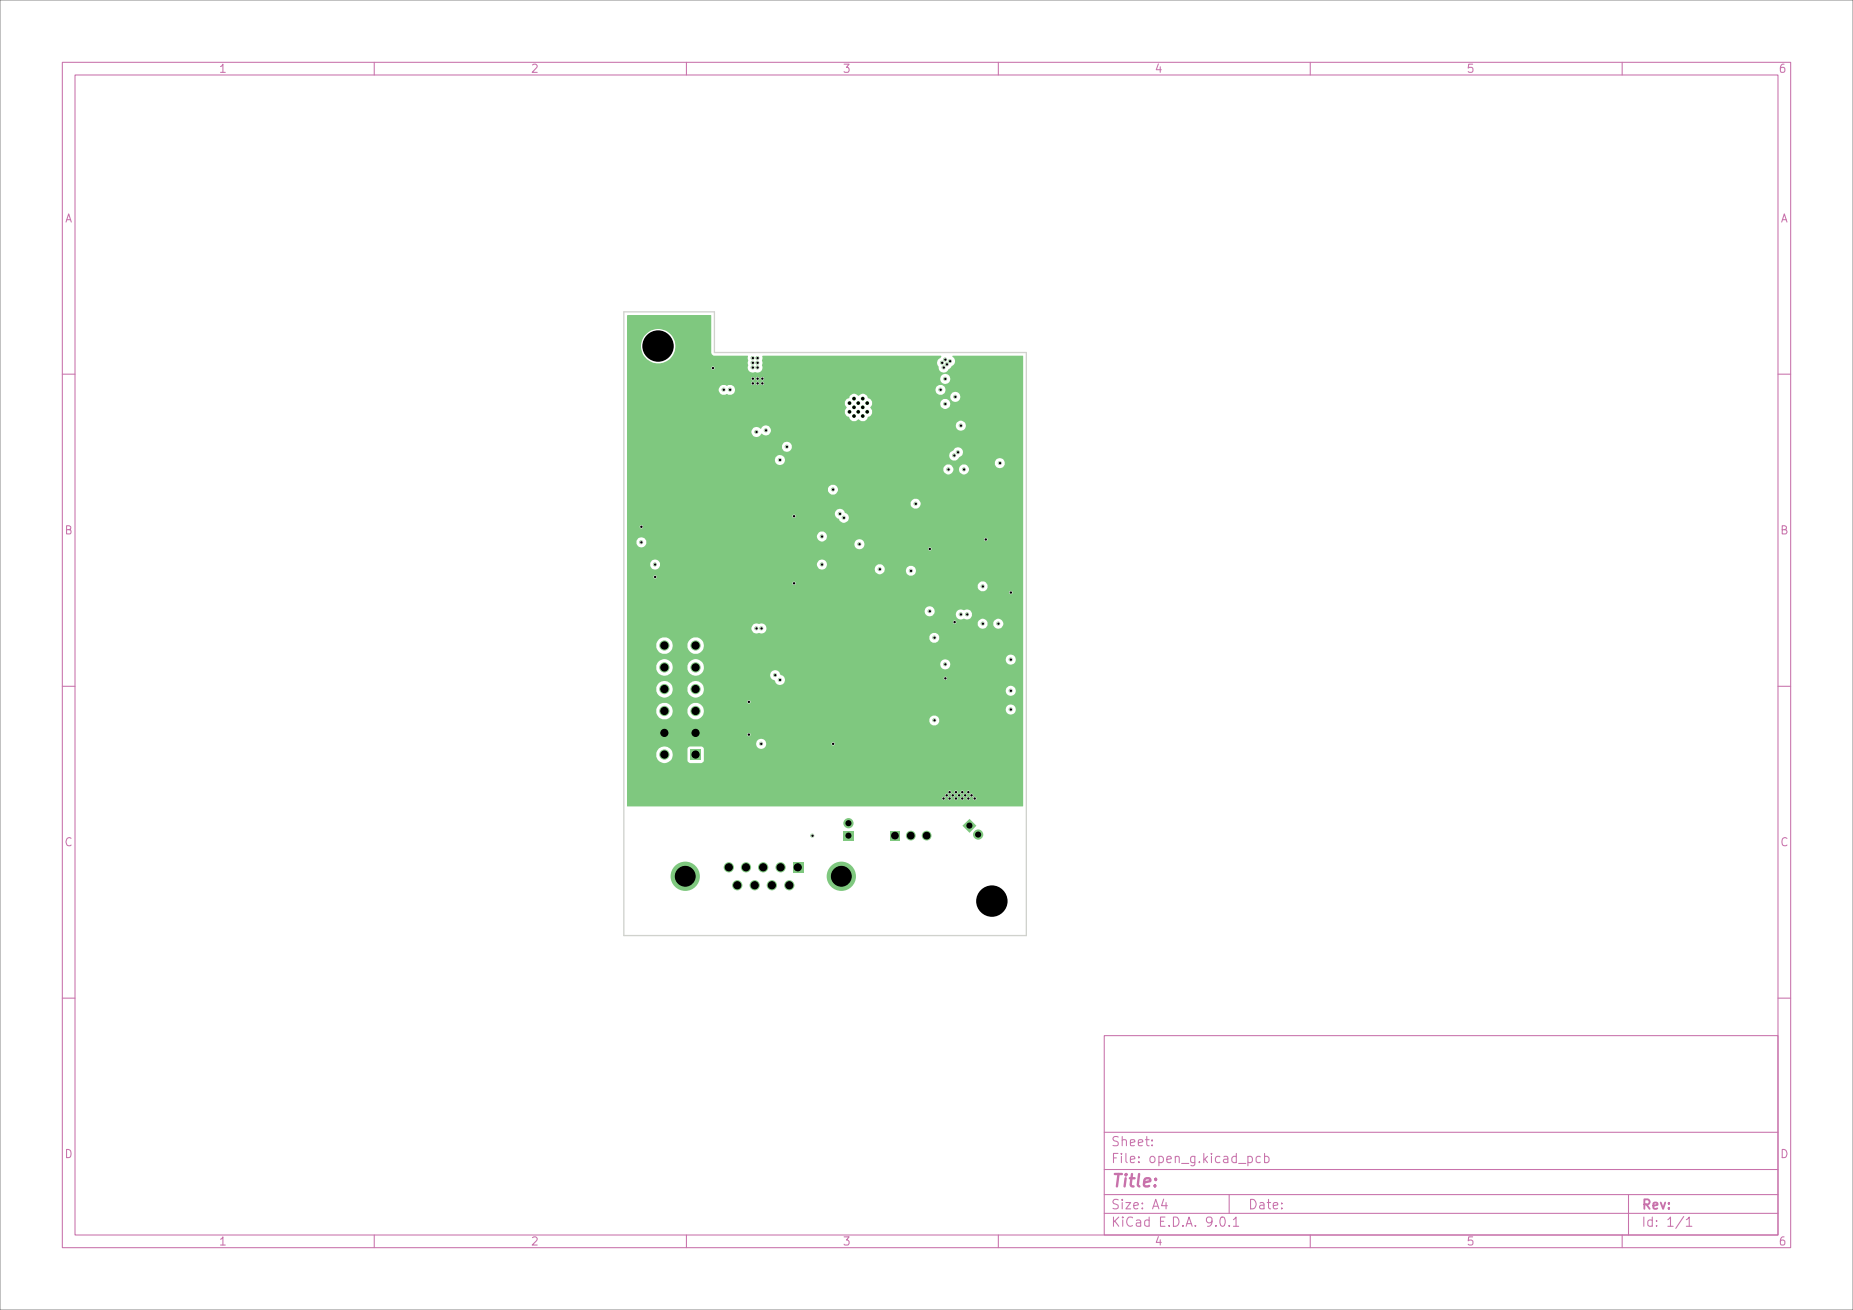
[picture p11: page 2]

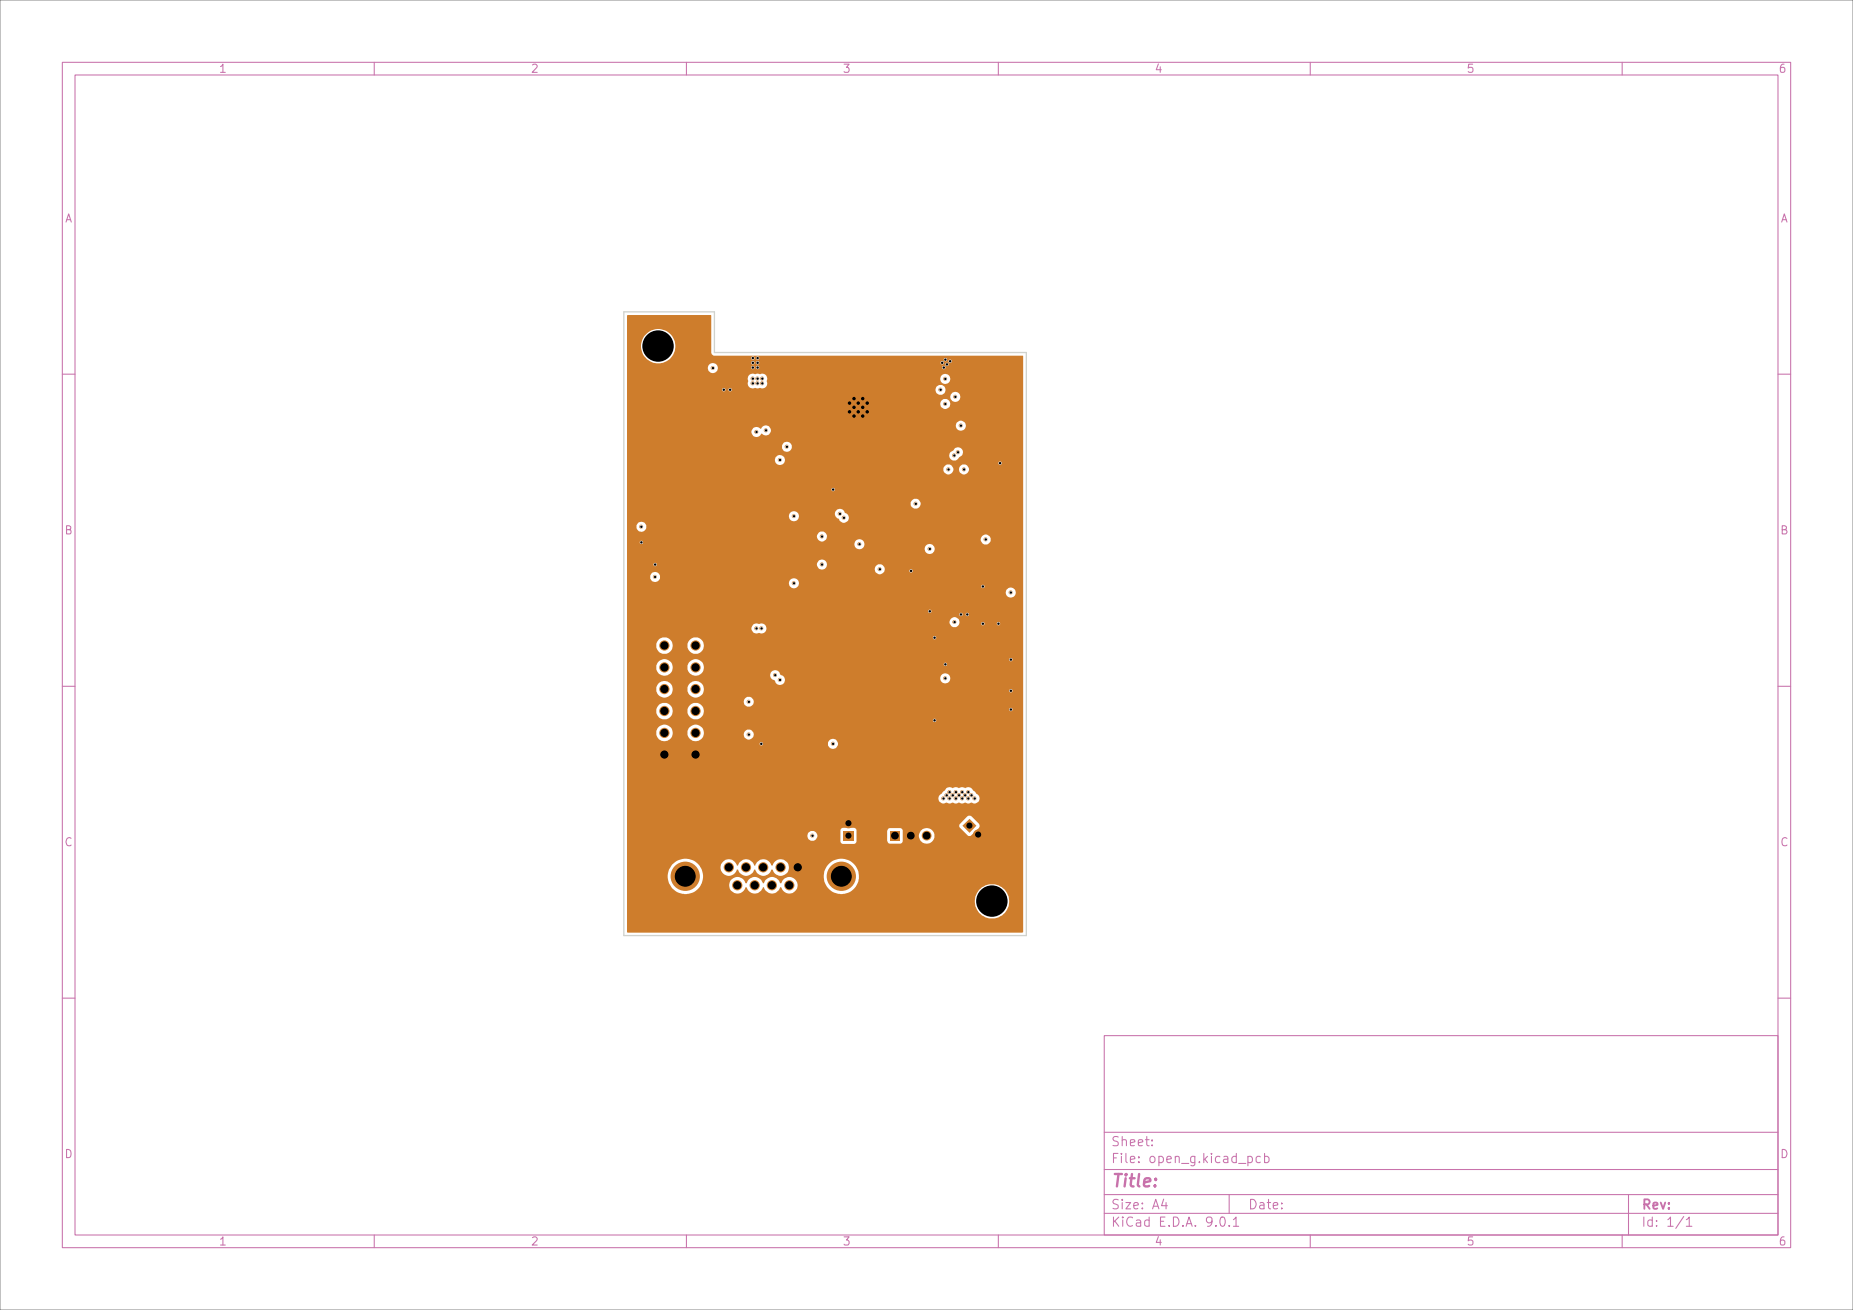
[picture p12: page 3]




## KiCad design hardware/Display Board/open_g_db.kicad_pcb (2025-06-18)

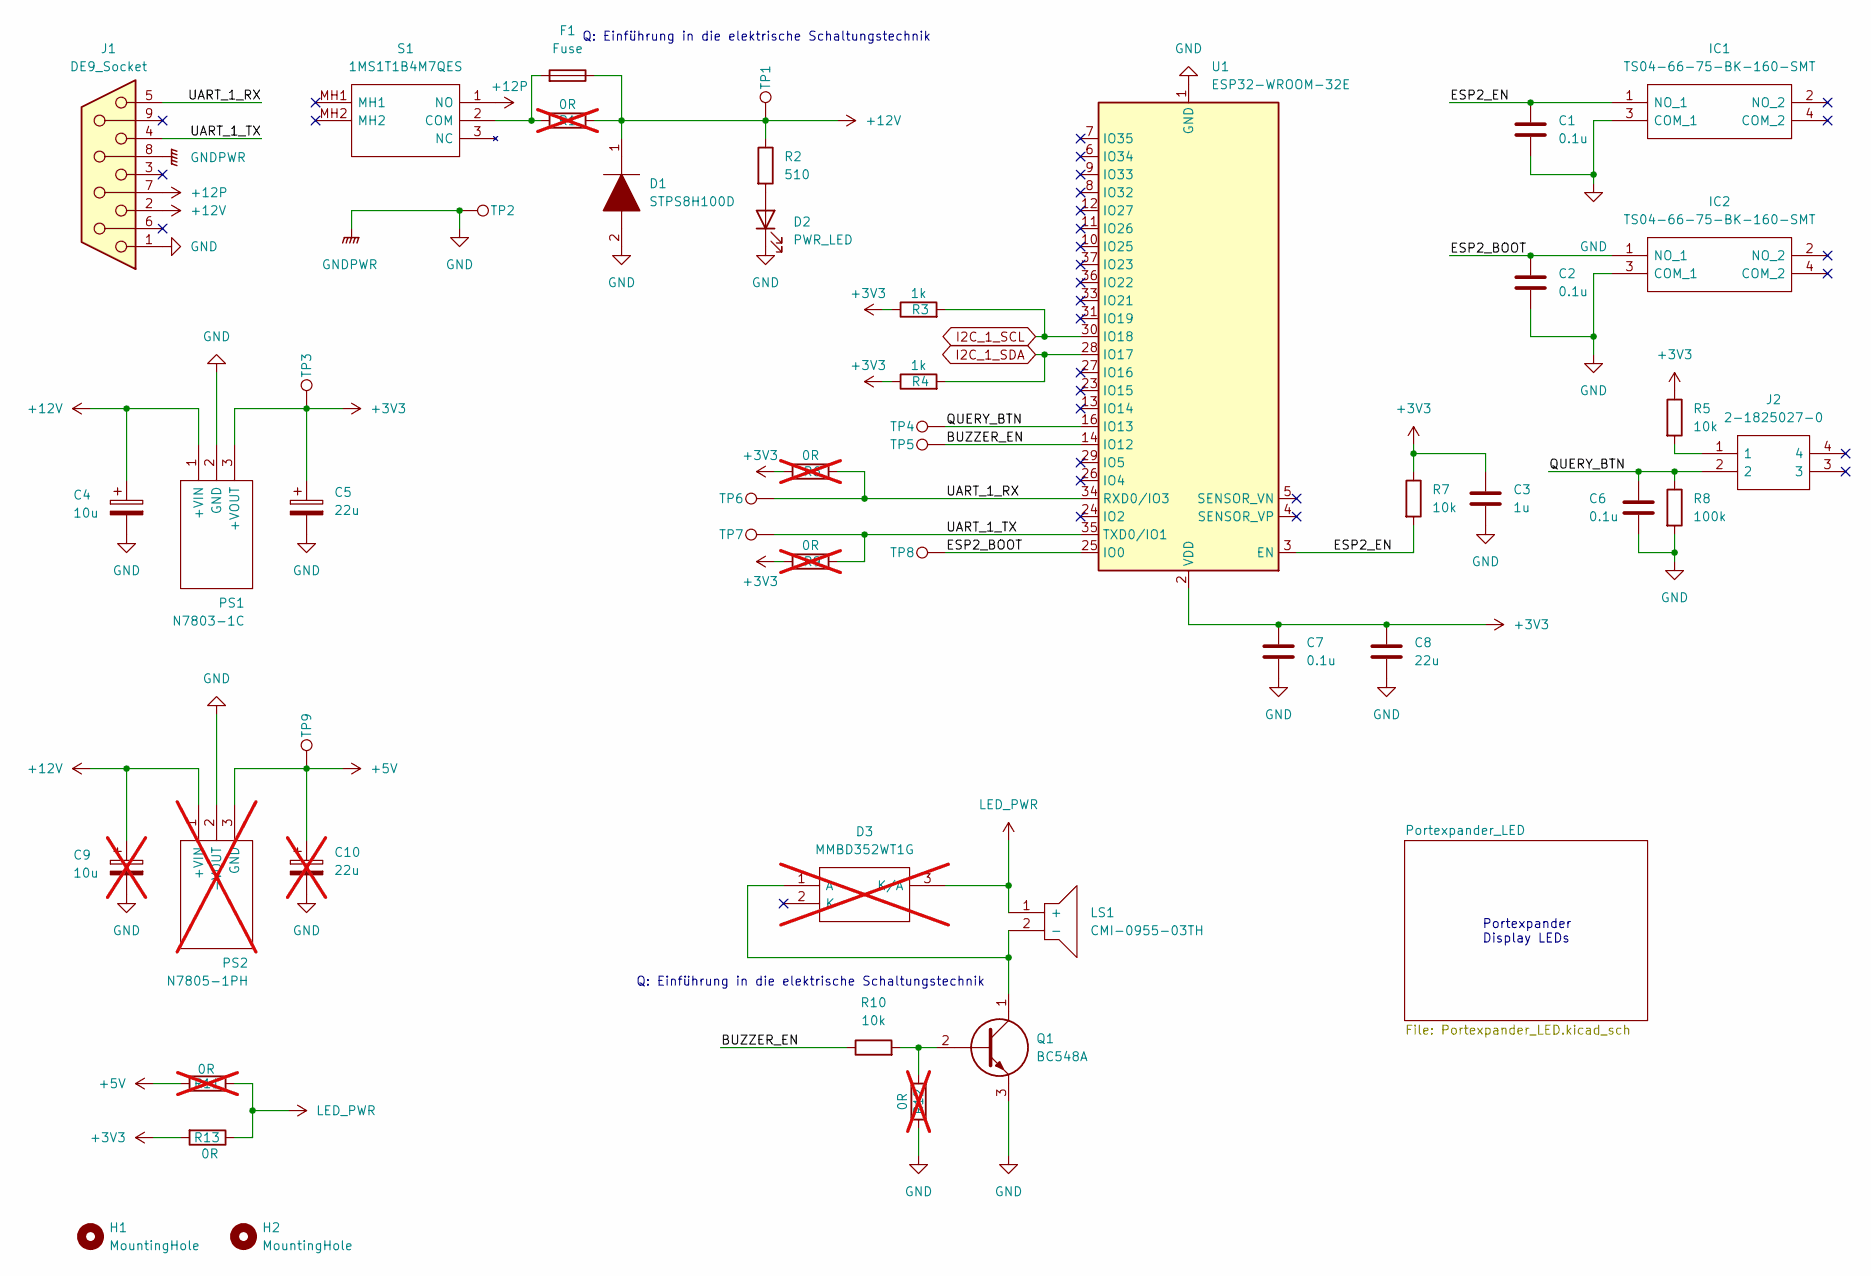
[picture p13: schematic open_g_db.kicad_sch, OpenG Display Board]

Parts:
C1, C2, C6, C7: 0.1u; C_0805_2012Metric_Pad1.18x1.45mm_HandSolder
C3: 1u; C_0805_2012Metric_Pad1.18x1.45mm_HandSolder
C4: 10u; CP_Radial_D5.0mm_P2.00mm
C5: 22u; CP_Radial_D5.0mm_P2.00mm
C8: 22u; C_0805_2012Metric_Pad1.18x1.45mm_HandSolder
C9: 10u; CP_Radial_D5.0mm_P2.00mm; not fitted
C10: 22u; CP_Radial_D5.0mm_P2.00mm; not fitted
D1: STPS8H100D; TO515P460X1020X2008-2P; Mouser Part Number 511-STPS8H100D
D2: PWR_LED; LED_D3.0mm_Horizontal_O1.27mm_Z2.0mm_Clear
D3: MMBD352WT1G; SOT65P220X100-3N; Mouser Part Number 863-MMBD352WT1G; not fitted
F1: Fuse; 3557-2
H1, H2: MountingHole; MountingHole_5mm_Pad_Via
IC1, IC2: TS04-66-75-BK-160-SMT; TS046675BK160SMT; Mouser Part Number 179-TS046675BK160SMT
J1: DE9_Socket; NFD17E09SAFC1DA
J2: 2-1825027-0; 218250270; Mouser Part Number 506-2-1825027-0
LS1: CMI-0955-03TH; CMI095503TH; Mouser Part Number 179-CMI-0955-03TH
PS1: N7803-1C; N78031C; Mouser Part Number 709-N7803-1C
PS2: N7805-1PH; N78031C; Mouser Part Number 709-N7805-1PH; not fitted
Q1: BC548A; Mouser Part Number 637-BC548A
R1, R6, R9, R11, R12: 0R; R_0805_2012Metric_Pad1.20x1.40mm_HandSolder; not fitted
R2: 510; R_0805_2012Metric_Pad1.20x1.40mm_HandSolder
R3, R4: 1k; R_0805_2012Metric_Pad1.20x1.40mm_HandSolder
R5, R7, R10: 10k; R_0805_2012Metric_Pad1.20x1.40mm_HandSolder
R8: 100k; R_0805_2012Metric_Pad1.20x1.40mm_HandSolder
R13: 0R; R_0805_2012Metric_Pad1.20x1.40mm_HandSolder
S1: 1MS1T1B4M7QES; Mouser Part Number 118-1MS1T1B4M7QES
TP1, TP2, TP3, TP4, TP5, TP6, TP7, TP8, TP9: TestPoint; TestPoint_Pad_D2.5mm
U1: ESP32-WROOM-32E

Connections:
+3V3: C3.1, C5.1, C7.1, C8.1, PS1.3 (+VOUT), R3.1, R4.1, R5.1, R6.1, R7.1, R9.1, R13.2, TP3.1, U1.2 (VDD); also elsewhere on the board
+5V: C10.1, PS2.3 (GND), R11.2, TP9.1
+12P: J1.7, S1.1 (NO)
+12V: C4.1, C9.1, D1.1, F1.1, J1.2, PS1.1 (+VIN), PS2.1 (+VIN), R1.2, R2.1, TP1.1
/BUZZER_EN: R10.1, TP5.1, U1.14 (IO12)
/ESP2_BOOT: C2.1, IC2.1 (NO_1), TP8.1, U1.25 (IO0)
/ESP2_EN: C1.1, IC1.1 (NO_1), R7.2, U1.3 (EN)
/QUERY_BTN: C6.1, J2.2, R8.1, TP4.1, U1.16 (IO13)
/UART_1_RX: J1.5, R6.2, TP6.1, U1.34 (RXD0/IO3)
/UART_1_TX: J1.4, R9.2, TP7.1, U1.35 (TXD0/IO1)
GND: C1.2, C2.2, C3.2, C4.2, C5.2, C6.2, C7.2, C8.2, C9.2, C10.2, D1.2, D2.1 (K), IC1.3 (COM_1), IC2.3 (COM_1), J1.1, J1.8, PS1.2 (GND), PS2.2 (-VOUT), Q1.3, R8.2, R12.1, TP2.1, U1.1 (GND), U1.15 (GND), U1.38 (GND), U1.39 (GND); also elsewhere on the board
I2C_1_SCL: R3.2, U1.30 (IO18); also elsewhere on the board
I2C_1_SDA: R4.2, U1.28 (IO17); also elsewhere on the board
LED_PWR: D3.3 (K/A), LS1.1 (+), R11.1, R13.1; also elsewhere on the board
unnamed: D2.2 (A), R2.2
unnamed: D3.1 (A), LS1.2 (-), Q1.1
unnamed: J2.1, R5.2
unnamed: Q1.2, R10.2, R12.2
unnamed: F1.2, R1.1, S1.2 (COM)

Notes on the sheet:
Portexpander Display LEDs
Q: Einführung in die elektrische Schaltungstechnik

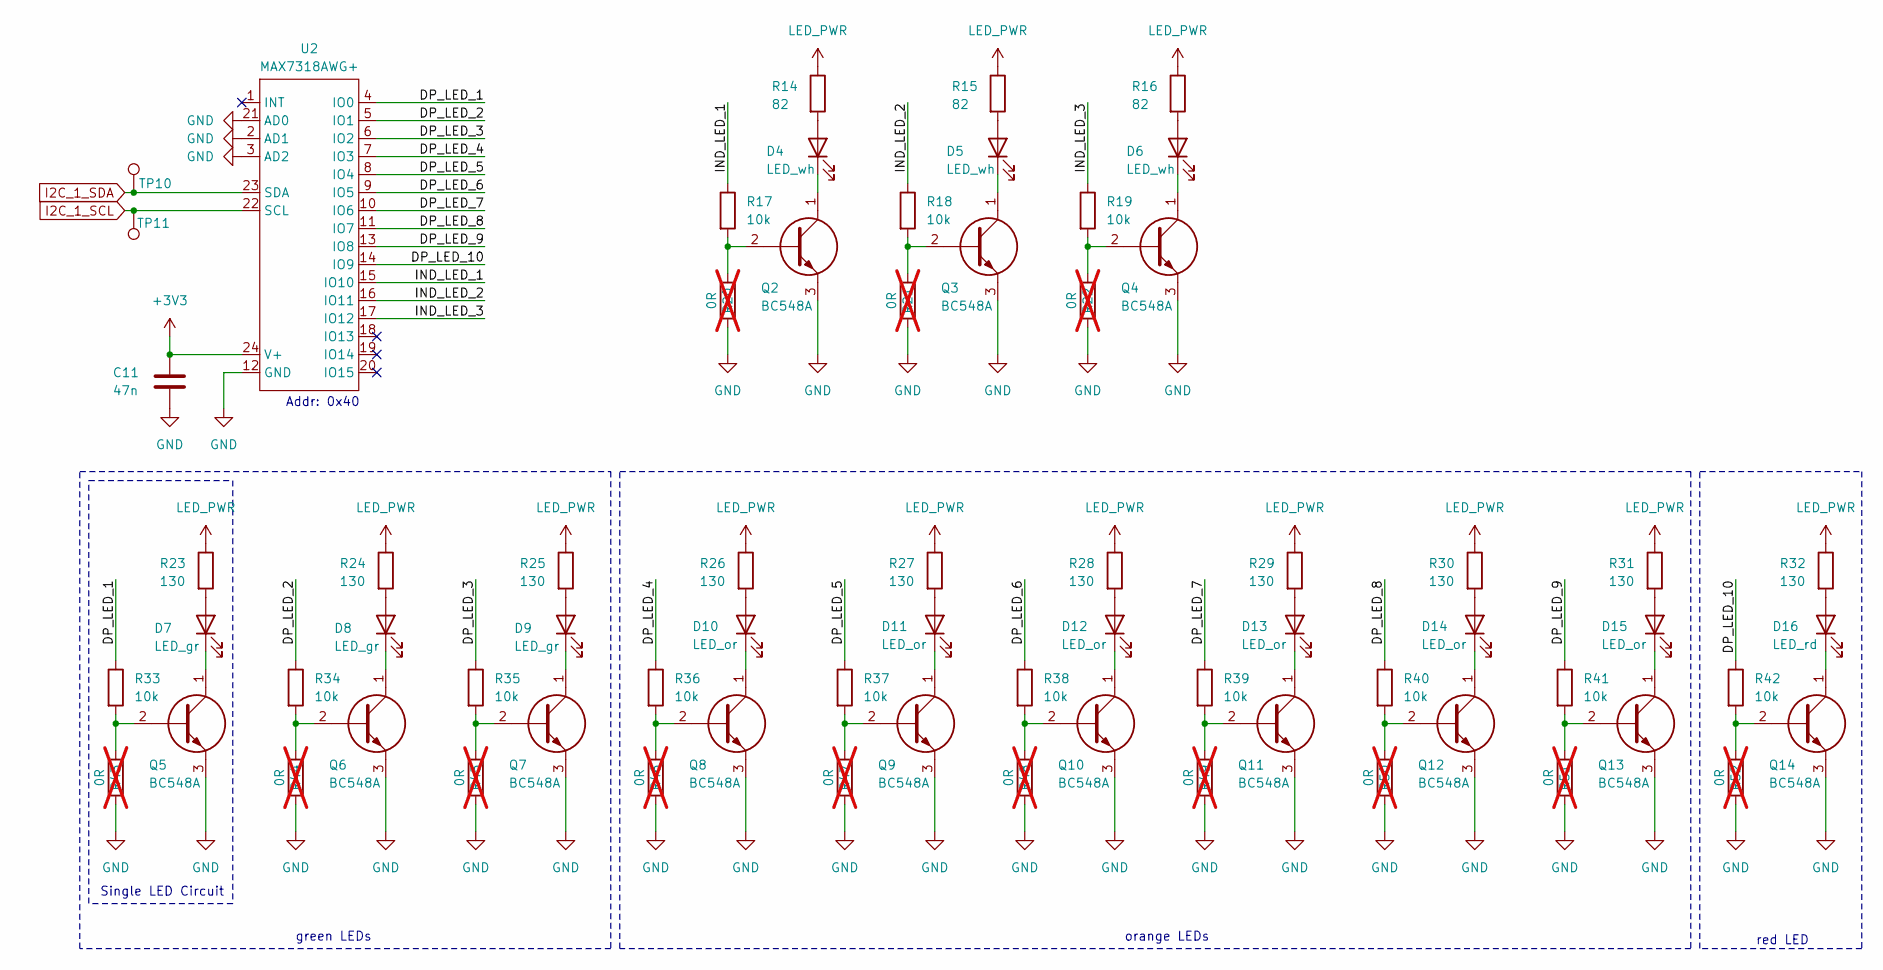
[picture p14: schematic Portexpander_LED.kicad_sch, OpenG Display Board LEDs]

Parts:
C11: 47n; C_0805_2012Metric_Pad1.18x1.45mm_HandSolder
D4, D5, D6: LED_wh; LED_D3.0mm_Horizontal_O1.27mm_Z2.0mm_Clear
D7, D8, D9: LED_gr; LED_D3.0mm_Horizontal_O1.27mm_Z2.0mm_Clear
D10, D11, D12, D13, D14, D15: LED_or; LED_D3.0mm_Horizontal_O1.27mm_Z2.0mm_Clear
D16: LED_rd; LED_D3.0mm_Horizontal_O1.27mm_Z2.0mm_Clear
Q2, Q3, Q4, Q5, Q6, Q7, Q8, Q9, Q10, Q11, Q12, Q13, Q14: BC548A; Mouser Part Number 637-BC548A
R14, R15, R16: 82; R_0805_2012Metric_Pad1.20x1.40mm_HandSolder
R17, R18, R19, R33, R34, R35, R36, R37, R38, R39, R40, R41, R42: 10k; R_0805_2012Metric_Pad1.20x1.40mm_HandSolder
R20, R21, R22, R43, R44, R45, R46, R47, R48, R49, R50, R51, R52: 0R; R_0805_2012Metric_Pad1.20x1.40mm_HandSolder; not fitted
R23, R24, R25, R26, R27, R28, R29, R30, R31, R32: 130; R_0805_2012Metric_Pad1.20x1.40mm_HandSolder
TP10, TP11: TestPoint; TestPoint_Pad_D2.5mm
U2: MAX7318AWG+; SOIC-24W_7.5x15.4mm_P1.27mm

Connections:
+3V3: C11.2, U2.24 (V+); also elsewhere on the board
/Portexpander_LED/DP_LED_1: R33.1, U2.4 (IO0)
/Portexpander_LED/DP_LED_2: R34.1, U2.5 (IO1)
/Portexpander_LED/DP_LED_3: R35.1, U2.6 (IO2)
/Portexpander_LED/DP_LED_4: R36.1, U2.7 (IO3)
/Portexpander_LED/DP_LED_5: R37.1, U2.8 (IO4)
/Portexpander_LED/DP_LED_6: R38.1, U2.9 (IO5)
/Portexpander_LED/DP_LED_7: R39.1, U2.10 (IO6)
/Portexpander_LED/DP_LED_8: R40.1, U2.11 (IO7)
/Portexpander_LED/DP_LED_9: R41.1, U2.13 (IO8)
/Portexpander_LED/DP_LED_10: R42.1, U2.14 (IO9)
/Portexpander_LED/IND_LED_1: R17.1, U2.15 (IO10)
/Portexpander_LED/IND_LED_2: R18.1, U2.16 (IO11)
/Portexpander_LED/IND_LED_3: R19.1, U2.17 (IO12)
GND: C11.1, Q2.3, Q3.3, Q4.3, Q5.3, Q6.3, Q7.3, Q8.3, Q9.3, Q10.3, Q11.3, Q12.3, Q13.3, Q14.3, R20.1, R21.1, R22.1, R43.1, R44.1, R45.1, R46.1, R47.1, R48.1, R49.1, R50.1, R51.1, R52.1, U2.2 (AD1), U2.3 (AD2), U2.12 (GND), U2.21 (AD0); also elsewhere on the board
I2C_1_SCL: TP11.1, U2.22 (SCL); also elsewhere on the board
I2C_1_SDA: TP10.1, U2.23 (SDA); also elsewhere on the board
LED_PWR: R14.1, R15.1, R16.1, R23.1, R24.1, R25.1, R26.1, R27.1, R28.1, R29.1, R30.1, R31.1, R32.1; also elsewhere on the board
unnamed: D4.2 (A), R14.2
unnamed: D4.1 (K), Q2.1
unnamed: D5.2 (A), R15.2
unnamed: D5.1 (K), Q3.1
unnamed: D6.2 (A), R16.2
unnamed: D6.1 (K), Q4.1
unnamed: D7.2 (A), R23.2
unnamed: D7.1 (K), Q5.1
unnamed: D8.2 (A), R24.2
unnamed: D8.1 (K), Q6.1
unnamed: D9.2 (A), R25.2
unnamed: D9.1 (K), Q7.1
unnamed: D10.2 (A), R26.2
unnamed: D10.1 (K), Q8.1
unnamed: D11.2 (A), R27.2
unnamed: D11.1 (K), Q9.1
unnamed: D12.2 (A), R28.2
unnamed: D12.1 (K), Q10.1
unnamed: D13.2 (A), R29.2
unnamed: D13.1 (K), Q11.1
unnamed: D14.2 (A), R30.2
unnamed: D14.1 (K), Q12.1
unnamed: D15.2 (A), R31.2
unnamed: D15.1 (K), Q13.1
unnamed: D16.2 (A), R32.2
unnamed: D16.1 (K), Q14.1
unnamed: Q2.2, R17.2, R20.2
unnamed: Q3.2, R18.2, R21.2
unnamed: Q4.2, R19.2, R22.2
unnamed: Q5.2, R33.2, R43.2
unnamed: Q6.2, R34.2, R44.2
unnamed: Q7.2, R35.2, R45.2
unnamed: Q8.2, R36.2, R46.2
unnamed: Q9.2, R37.2, R47.2
unnamed: Q10.2, R38.2, R48.2
unnamed: Q11.2, R39.2, R49.2
unnamed: Q12.2, R40.2, R50.2
unnamed: Q13.2, R41.2, R51.2
unnamed: Q14.2, R42.2, R52.2

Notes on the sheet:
orange LEDs
green LEDs
red LED
Single LED Circuit
Addr: 0x40

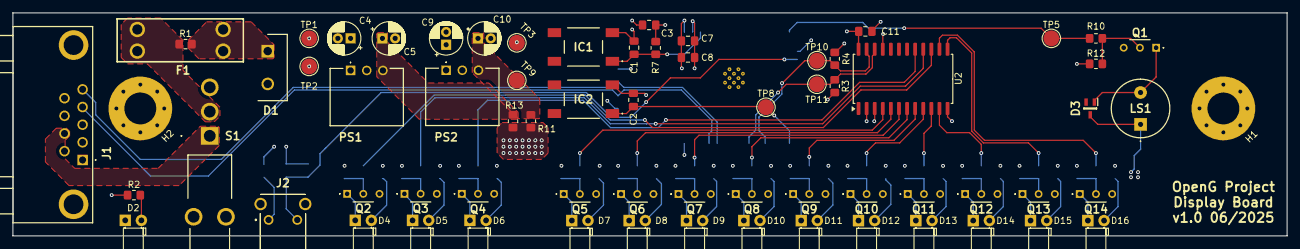
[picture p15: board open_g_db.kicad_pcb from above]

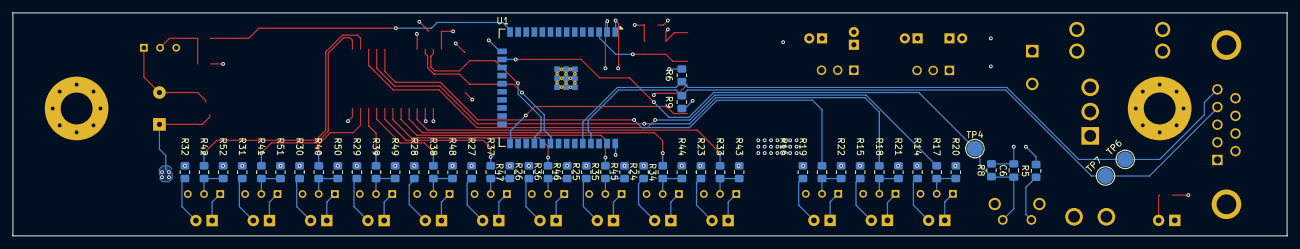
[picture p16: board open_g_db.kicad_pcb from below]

Board: 4 copper layers, 200.0 x 35.0 mm, 117 parts (48 on the bottom side), 71 nets.

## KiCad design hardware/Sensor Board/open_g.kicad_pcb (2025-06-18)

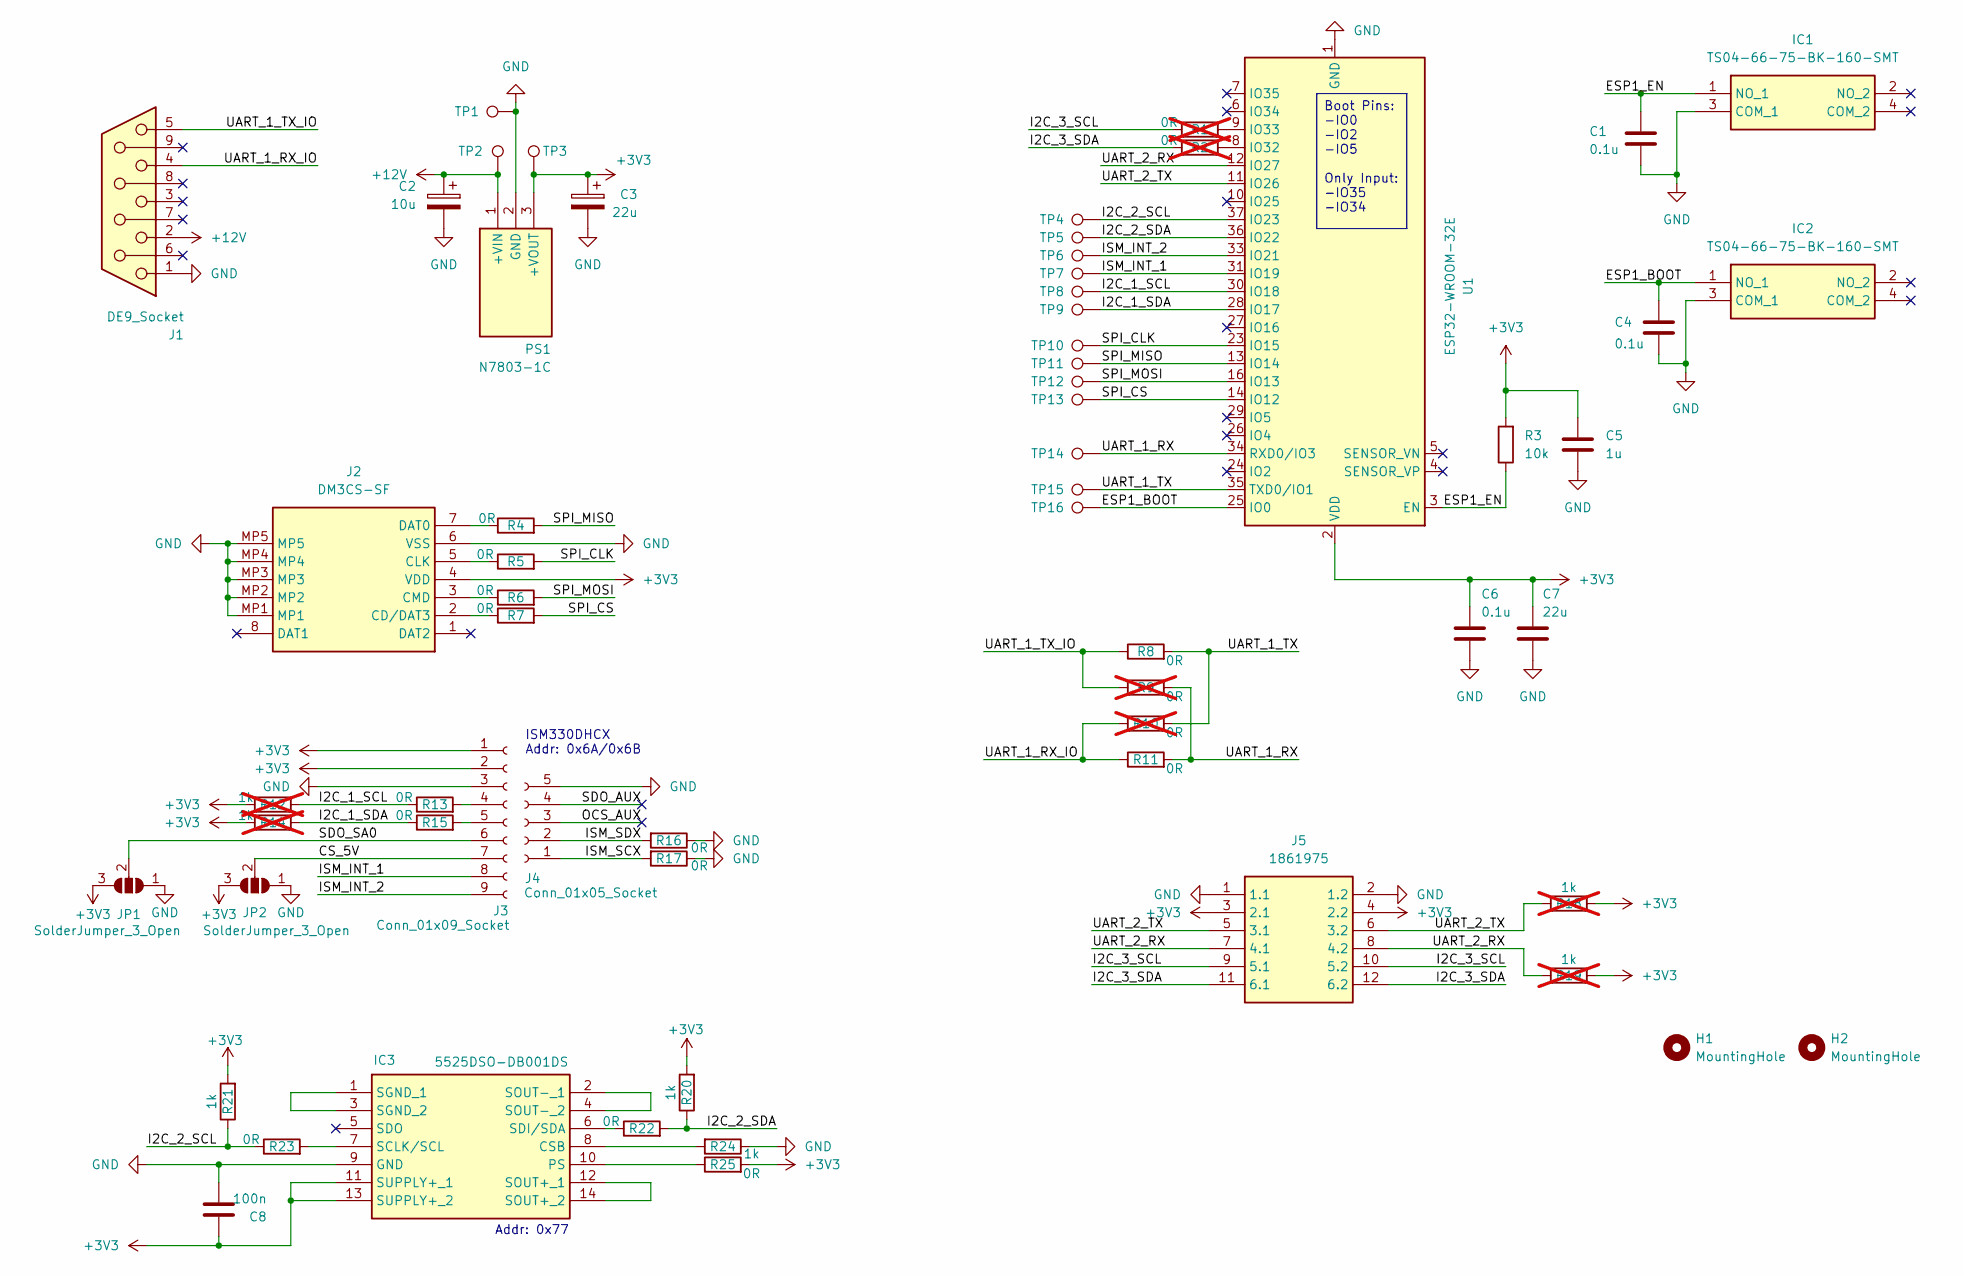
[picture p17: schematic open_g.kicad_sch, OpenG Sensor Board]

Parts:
C1, C4, C6: 0.1u; C_0805_2012Metric_Pad1.18x1.45mm_HandSolder
C2: 10u; CP_Radial_D5.0mm_P2.00mm
C3: 22u; CP_Radial_D5.0mm_P2.00mm
C5: 1u; C_0805_2012Metric_Pad1.18x1.45mm_HandSolder
C7: 22u; C_0805_2012Metric_Pad1.18x1.45mm_HandSolder
C8: 100n; C_0805_2012Metric_Pad1.18x1.45mm_HandSolder
H1, H2: MountingHole; MountingHole_5mm_Pad_Via
IC1, IC2: TS04-66-75-BK-160-SMT; TS046675BK160SMT; Mouser Part Number 179-TS046675BK160SMT
IC3: 5525DSO-DB001DS; SOIC-14W_7.5x9mm_P1.27mm; Mouser Part Number 824-5525DSO-DB001DS
J1: DE9_Socket; NFD17E09SAFC1DA
J2: DM3CS-SF; DM3CSSF; Mouser Part Number 798-DM3CSSF
J3: Conn_01x09_Socket; PinSocket_1x09_P2.54mm_Vertical
J4: Conn_01x05_Socket; PinSocket_1x05_P2.54mm_Vertical
J5: 1861975; PC1861975; Mouser Part Number 651-1861975
JP1, JP2: SolderJumper_3_Open; SolderJumper-3_P2.0mm_Open_TrianglePad1.0x1.5mm
PS1: N7803-1C; N78031C; Mouser Part Number 709-N7803-1C
R1, R2, R9, R10: 0R; R_0805_2012Metric_Pad1.20x1.40mm_HandSolder; not fitted
R3: 10k; R_0805_2012Metric_Pad1.20x1.40mm_HandSolder
R4, R5, R6, R7, R8, R11, R13, R15, R16, R17, R22, R23, R25: 0R; R_0805_2012Metric_Pad1.20x1.40mm_HandSolder
R12, R14, R18, R19: 1k; R_0805_2012Metric_Pad1.20x1.40mm_HandSolder; not fitted
R20, R21, R24: 1k; R_0805_2012Metric_Pad1.20x1.40mm_HandSolder
TP1, TP2, TP3, TP4, TP5, TP6, TP7, TP8, TP9, TP10, TP11, TP12, TP13, TP14, TP15, TP16: TestPoint; TestPoint_Pad_D2.5mm
U1: ESP32-WROOM-32E; ESP32-WROOM-32D

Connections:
+3V3: C3.1, C5.1, C6.1, C7.1, C8.1, IC3.11 (SUPPLY+_1), IC3.13 (SUPPLY+_2), J2.4 (VDD), J3.1, J3.2, J5.3 (2.1), J5.4 (2.2), JP1.3 (B), JP2.3 (B), PS1.3 (+VOUT), R3.2, R12.2, R14.2, R18.2, R19.2, R20.2, R21.2, R25.2, TP3.1, U1.2 (VDD)
+12V: C2.1, J1.2, PS1.1 (+VIN), TP2.1
/CS_5V: J3.7, JP2.2 (C)
/ESP1_BOOT: C4.1, IC2.1 (NO_1), TP16.1, U1.25 (IO0)
/ESP1_EN: C1.1, IC1.1 (NO_1), R3.1, U1.3 (EN)
/I2C_1_SCL: R12.1, R13.1, TP8.1, U1.30 (IO18)
/I2C_1_SDA: R14.1, R15.1, TP9.1, U1.28 (IO17)
/I2C_2_SCL: R21.1, R23.1, TP4.1, U1.37 (IO23)
/I2C_2_SDA: R20.1, R22.2, TP5.1, U1.36 (IO22)
/I2C_3_SCL: J5.9 (5.1), J5.10 (5.2), R1.1
/I2C_3_SDA: J5.11 (6.1), J5.12 (6.2), R2.1
/ISM_INT_1: J3.8, TP7.1, U1.31 (IO19)
/ISM_INT_2: J3.9, TP6.1, U1.33 (IO21)
/ISM_SCX: J4.1, R17.2
/ISM_SDX: J4.2, R16.2
/OCS_AUX: J4.3
/SDO_AUX: J4.4
/SDO_SA0: J3.6, JP1.2 (C)
/SPI_CLK: R5.2, TP10.1, U1.23 (IO15)
/SPI_CS: R7.2, TP13.1, U1.14 (IO12)
/SPI_MISO: R4.2, TP11.1, U1.13 (IO14)
/SPI_MOSI: R6.2, TP12.1, U1.16 (IO13)
/UART_1_RX: R9.2, R11.2, TP14.1, U1.34 (RXD0/IO3)
/UART_1_RX_IO: J1.4, R10.1, R11.1
/UART_1_TX: R8.2, R10.2, TP15.1, U1.35 (TXD0/IO1)
/UART_1_TX_IO: J1.5, R8.1, R9.1
/UART_2_RX: J5.7 (4.1), J5.8 (4.2), R19.1, U1.12 (IO27)
/UART_2_TX: J5.5 (3.1), J5.6 (3.2), R18.1, U1.11 (IO26)
GND: C1.2, C2.2, C3.2, C4.2, C5.2, C6.2, C7.2, C8.2, IC1.3 (COM_1), IC2.3 (COM_1), IC3.9 (GND), J1.1, J2.6 (VSS), J2.MP1, J2.MP2, J2.MP3, J2.MP4, J2.MP5, J3.3, J4.5, J5.1 (1.1), J5.2 (1.2), JP1.1 (A), JP2.1 (A), PS1.2 (GND), R16.1, R17.1, R24.1, TP1.1, U1.1 (GND), U1.15 (GND), U1.38 (GND), U1.39 (GND)
unnamed: IC3.8 (CSB), R24.2
unnamed: IC3.10 (PS), R25.1
unnamed: IC3.7 (SCLK/SCL), R23.2
unnamed: IC3.6 (SDI/SDA), R22.1
unnamed: IC3.1 (SGND_1), IC3.3 (SGND_2)
unnamed: IC3.12 (SOUT+_1), IC3.14 (SOUT+_2)
unnamed: IC3.2 (SOUT-_1), IC3.4 (SOUT-_2)
unnamed: J2.2 (CD/DAT3), R7.1
unnamed: J2.5 (CLK), R5.1
unnamed: J2.3 (CMD), R6.1
unnamed: J2.7 (DAT0), R4.1
unnamed: J3.4, R13.2
unnamed: J3.5, R15.2
unnamed: R2.2, U1.8 (IO32)
unnamed: R1.2, U1.9 (IO33)

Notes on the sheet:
Addr: 0x77
ISM330DHCX Addr: 0x6A/0x6B
Boot Pins: -IO0 -IO2 -IO5 Only Input: -IO35 -IO34

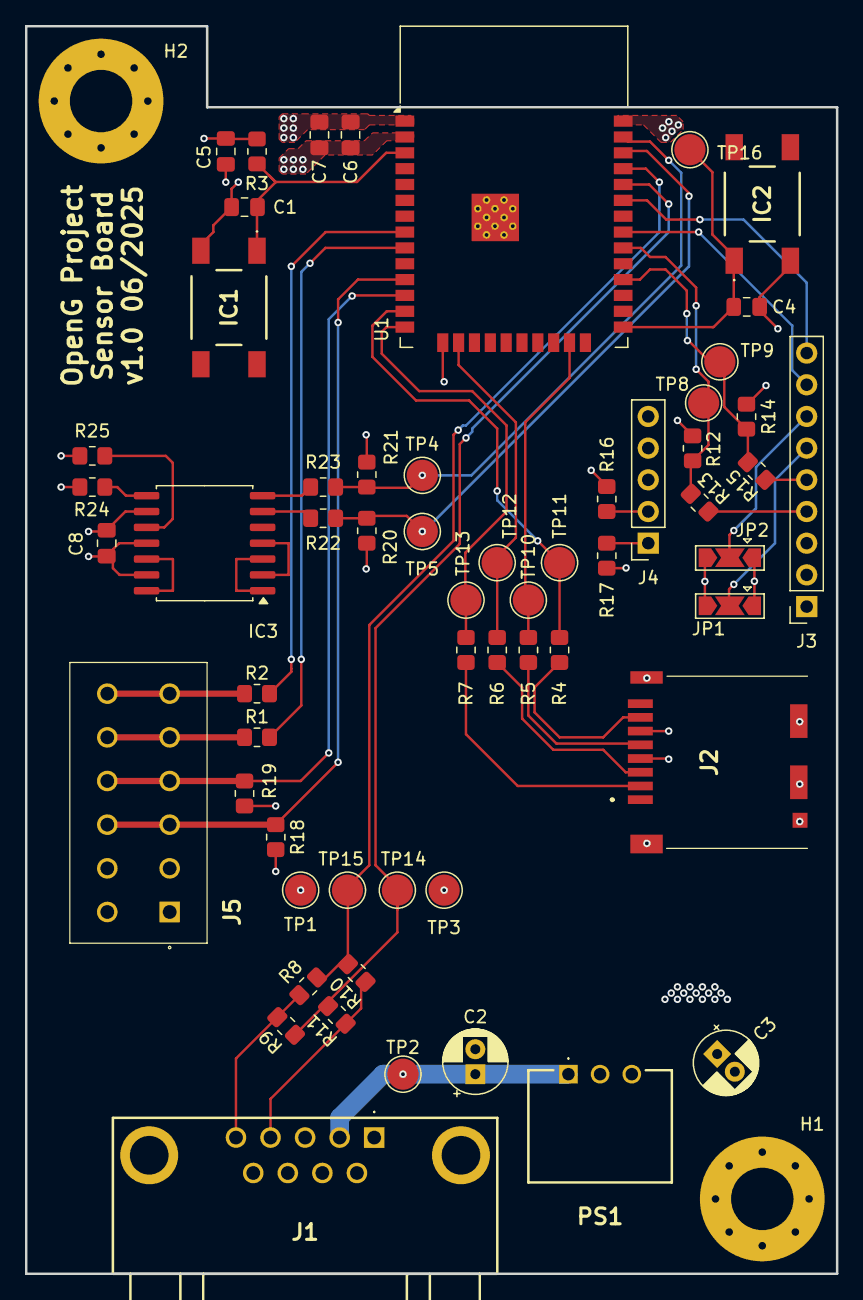
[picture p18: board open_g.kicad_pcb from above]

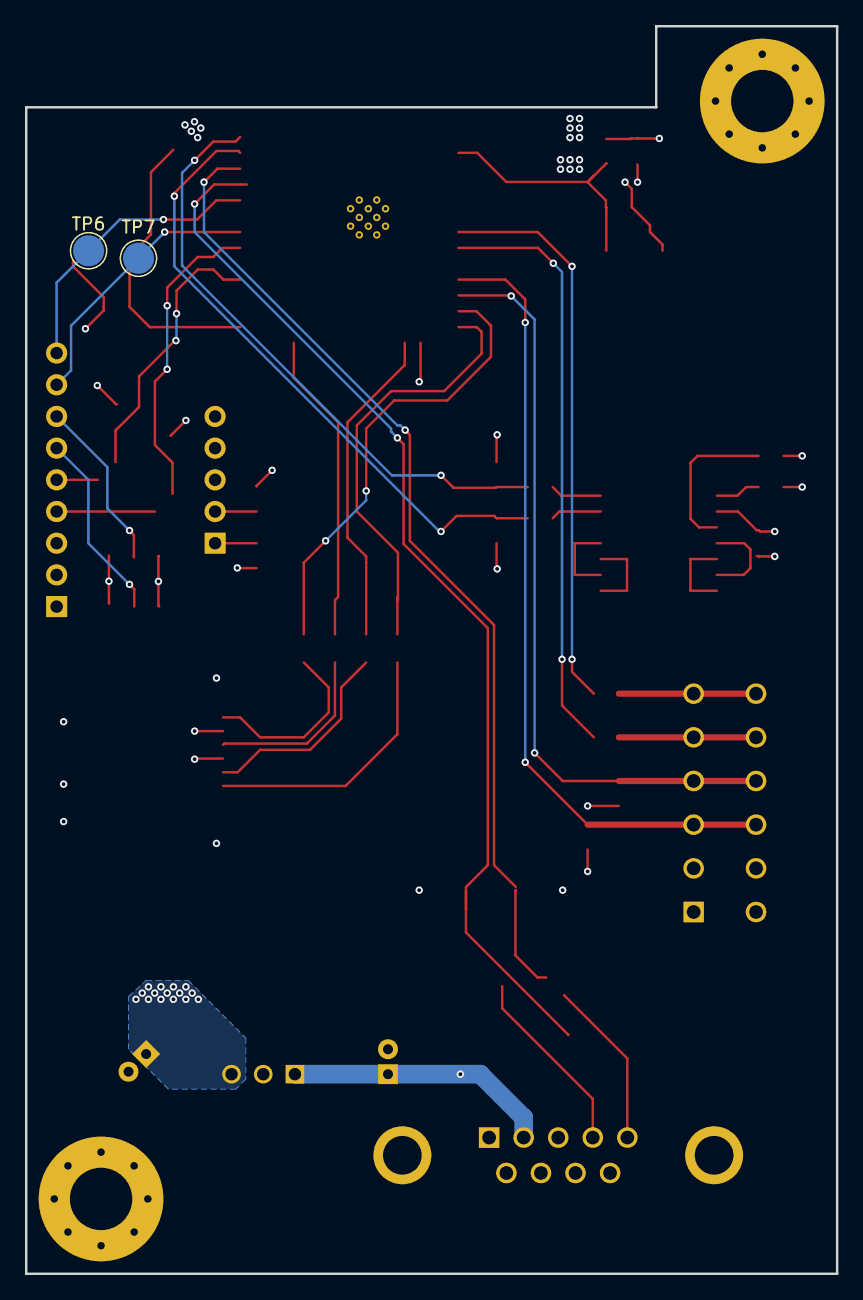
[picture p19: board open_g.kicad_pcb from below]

Board: 4 copper layers, 65.0 x 100.0 mm, 63 parts (2 on the bottom side), 42 nets.

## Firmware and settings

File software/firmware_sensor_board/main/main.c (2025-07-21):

/*
 * SPDX-FileCopyrightText: 2010-2022 Espressif Systems (Shanghai) CO LTD
 *
 * SPDX-License-Identifier: CC0-1.0
 * 
 * ESP-IDF Version 5.4.2
 * 
 * OpenG Project Sensor-Board Test-Code
 * Date: 07.07.2025
 * 
 * TODO: Implement Button (short and long press. Calibration)
 * 
 */

 
#include "I2C.h"
#include "sd_card.h"
#include "UART.h"
#include "MQTT.h"

#include <stdio.h>
#include <inttypes.h>
#include "sdkconfig.h"
#include "freertos/FreeRTOS.h"
#include "freertos/task.h"
#include "esp_system.h"




void lwd_task(void * args){

    vTaskDelay(pdMS_TO_TICKS(500));
    xSemaphoreTake(init_semaphor, portMAX_DELAY);

    vSemaphoreDelete(init_semaphor);

    uint8_t load_percent = 0;

    float m_p = (module_config.g_v_ne_p - module_config.g_max_p)/(module_config.v_ne-module_config.v_g_max);
    float m_n = (module_config.g_v_ne_n - module_config.g_max_n)/(module_config.v_ne-module_config.v_g_max);
    float b_p = (module_config.g_max_p)-(m_p*module_config.v_g_max);
    float b_n = (module_config.g_max_n)-(m_n*module_config.v_g_max);

    TickType_t xLWT = xTaskGetTickCount();
    while(1){

        float velocity = 0;
        xQueueReceive(system_velocity_ias_kmh, &velocity, portMAX_DELAY);
        float acc = 0;
        xQueueReceive(system_acceleration_norm_g, &acc, portMAX_DELAY);

        if(s_wifi_event_group != NULL){
            if(((uint8_t) xEventGroupGetBits(s_wifi_event_group) & MQTT_CONNECTED_BIT) == MQTT_CONNECTED_BIT){

                char velocity_str[10];
                snprintf(velocity_str, 10, "%.0f", velocity);
                publish_data("/speed", velocity_str, 2, 0);
                char acc_str[10];
                snprintf(acc_str, 10, "%.2f", acc);
                publish_data("/acc", acc_str, 2, 0);

            }
        }
        

        // printf("acc= %+0.2f \t v= %.0f\n", acc, velocity);
        load_percent = 0;

        if(acc >= 0){
            load_percent = (uint8_t) (acc / (m_p*velocity+b_p) * 100);
        }
        else{
            load_percent = (uint8_t) abs(acc / (m_n*velocity+b_n) * 100);
        }

        if(load_percent > load_watchdog_values.load_percentage){
            lwd_t values = {0};
            values.load_percentage = load_percent;
            values.g_absolute = acc;
            values.v_absolute = velocity;

            update_lwd_values(values);
        }

        if(load_percent >= 100){
            bool alarm = true;
            xQueueOverwrite(alarm_queue, &alarm);
        }

        // printf("Load: %d\n", load_percent);

        xQueueSend(load_queue, &load_percent, portMAX_DELAY);

        vTaskDelayUntil(&xLWT, pdMS_TO_TICKS(10));

    }

    vTaskDelete(NULL);
}


void app_main(void)
{
    init_semaphor = xSemaphoreCreateBinary();
    xSemaphoreGive(init_semaphor);

    load_queue = xQueueCreate(1, sizeof(uint8_t));
    alarm_queue = xQueueCreate(1, sizeof(bool));
    bool alarm_q = false;
    bool btn_q = false;
    xQueueOverwrite(alarm_queue, &alarm_q);
    button_queue = xQueueCreate(1, sizeof(bool));
    xQueueOverwrite(button_queue, &btn_q);

    fLED_event_group = xEventGroupCreate();

    xTaskCreate(sd_card_task, "Run SD", 1024*32, NULL, 10, NULL);

    i2c_master_bus_handle_t bus_handle;
    i2c_master_init_bus(&bus_handle);

    xTaskCreate(ism330dhcx_task, "Run ISM330DHCX", 4096, (void*) bus_handle, 10, &IMS330DHCX_Handle);

    i2c_master_bus_handle_t bus_2_handler;
    i2c_master_init_bus_2(&bus_2_handler);

    xTaskCreate(ms5525dso_task, "Run MS5525DSO", 4096, (void*) bus_2_handler, 10, &MS5525DSO_Handle);


    xTaskCreate(lwd_task, "Rund LWD", 4096, NULL, 8, NULL);

    xTaskCreate(uart_event_task, "RUN UART", 2048, NULL, 11, NULL);
  
    

}

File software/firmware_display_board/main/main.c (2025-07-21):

/*
 * SPDX-FileCopyrightText: 2010-2022 Espressif Systems (Shanghai) CO LTD
 *
 * SPDX-License-Identifier: CC0-1.0
 * 
 * ESP-IDF Version 5.4.2
 * 
 * OpenG Project Display-Board Test-Code
 * Date: 07.07.2025
 * 
 */

#include <stdio.h>
#include <inttypes.h>
#include "sdkconfig.h"
#include "freertos/FreeRTOS.h"
#include "freertos/task.h"
#include "esp_system.h"
#include "max7318.h"
#include "buzzer.h"
#include "UART.h"

void app_main(void){

    button_queue = xQueueCreate(1, sizeof(bool));
    load_queue = xQueueCreate(1, sizeof(uint8_t));
    alarm_queue = xQueueCreate(1, sizeof(bool));

    i2c_master_bus_handle_t bus_1_handler;
    i2c_master_init_bus(&bus_1_handler);

    xTaskCreate(max7318awg_task, "Run MAX7318AWG+", 4096, (void*) bus_1_handler, 10, &MAX7318AWG_Handle);

    xTaskCreate(buzzer_task, "Run Buzzer", 2048, NULL, 10, &BUZZER_HANDLE);

    xTaskCreate(uart_event_task, "Run UART", 2048, NULL, 9, NULL);

}

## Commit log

2025-06-17 added v1.0 schematics, layouts, gerbers, libs and other files
    [Portexpander_LED.kicad_sch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]
2025-06-18 added README and minor changes
    [open_g-B_Cu.gbr, open_g-B_Mask.gbr, open_g-B_Paste.gbr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]
2025-07-21 added gerbers and initial for firmware; changed README
    [Portexpander_LED.kicad_sch, open_g.csv, open_g.kicad_sch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]

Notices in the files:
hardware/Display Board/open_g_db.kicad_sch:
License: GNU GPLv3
